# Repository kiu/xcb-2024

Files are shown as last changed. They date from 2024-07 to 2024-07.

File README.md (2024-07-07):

# xcb-2024
The cross communication badge (xcb) was created for a two day internal company conference. Its main purpose was to gamify communication and networking across the 150 participants.

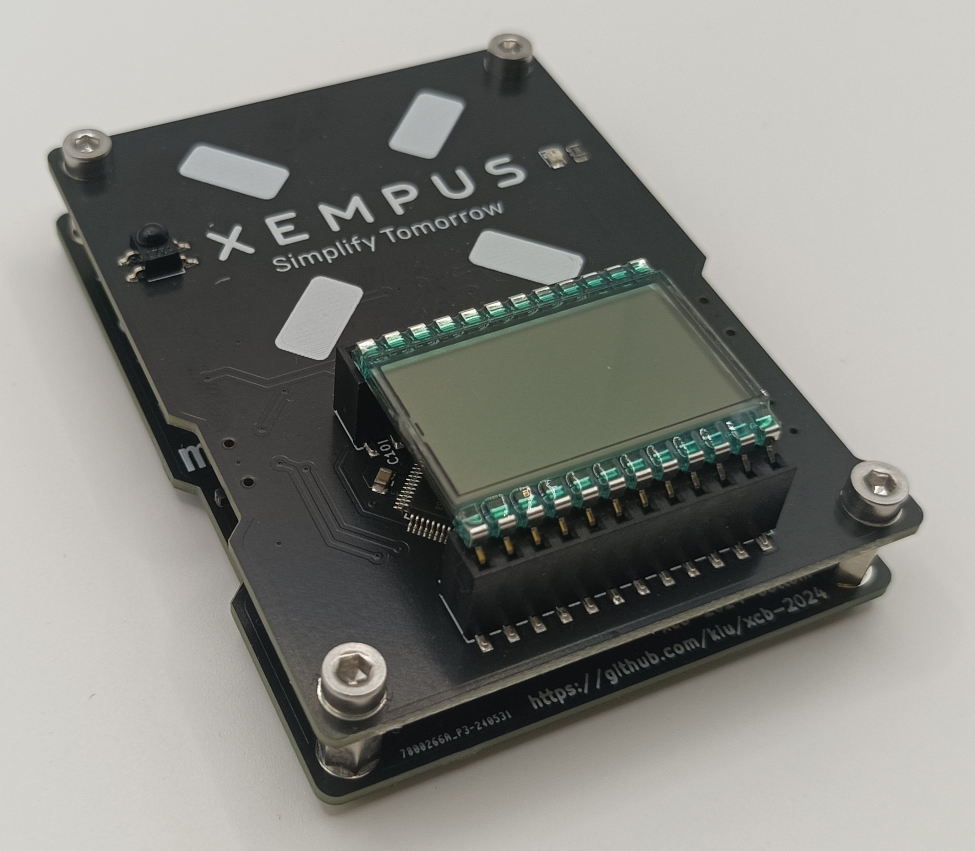
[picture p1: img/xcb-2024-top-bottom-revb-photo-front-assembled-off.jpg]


<sup>Additional images can be found in the [img](img/) directory</sup>

# Features
The badge features three modes: Conference, Play and Sensor.

In <ins>conference mode</ins> each badge transmits its unique ID every 30 seconds. Any badge receiving two transmissions from the same badge within 100 seconds will count this as a unique contact. Due to limited infrared power, close proximity between sender and receiver is assumed. The amount of unique contacts is displayed on the LCD screen to gamify in-person encounters.

In addition secret badges are hidden at the event location, offering a treasure hunt for those who want to explore beyond the main conference tracks. The needed hints are printed on [flyers](xcb-2024-flyer.pdf) handed out with the badge. The discovery of these secret badges is encoded in the display as single segments to easily compare progress between participants.

It was important to me that the badge could be re-used after the conference so I added two additional modes.

In <ins>play mode</ins> the badge features a version of the popular game Simon https://en.wikipedia.org/wiki/Simon_(game) (in Germany known as Senso https://de.wikipedia.org/wiki/Senso_(Spiel)). People can chase a high score, which can also be displayed when in conference mode.

In <ins>sensor mode</ins> the badge transforms into a temperature and humidity display with min/max functionality. Powered by USB the badge can continue to operate in the home or office.

On the back of this stacked PCB assembly (preventing any electrical shorts while wearing) the participants can find a [silk screened word puzzle](img/xcb-2024-bottom-revb-render-back.png) containing the names of the employees of the company.

## Video
There is a short video highlighting all badge features on youtube: https://youtu.be/XA52-lHTVL4

<a href="http://www.youtube.com/watch?feature=player_embedded&v=XA52-lHTVL4" target="_blank">
	xcb-2024 on youtube
</a>

# Hardware
The hardware is [straight forward](kicad/xcb-2024-top-revb-schematic.png). Powered by two CR2032 coin cells or USB, a STM32, a three digit LCD display, an infrared receiver/transmitter, a buzzer, four capacitive touch buttons and a temperature and humidity sensor. All neatly packed into a wearable badge.

# Repository
- [datasheets](datasheets/): Datasheets of most components
- [firmware](firmware/): STM32CubeIDE project
- [kicad](kicad/): KiCad schematics, PCBs and BOM for single+panelized badge and flash adapter
- [tools](tools/): Helper scripts to generate buzzer note table, mass flashing with auto ID increment and masked word puzzle generator

# License
This project is licensed under the Creative Commons Attribution-NonCommercial 3.0 Unported (CC BY-NC 3.0) license. Use of the company name and company logo in any form is not covered by this license.

# Thanks <3
Thanks to Fabian for helping out on the flyer design and Andrii, Maria (+Sebastian), Monika, Niels (+Milla) for working hard doing the final mechanical assembly!

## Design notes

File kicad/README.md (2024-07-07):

# kicad

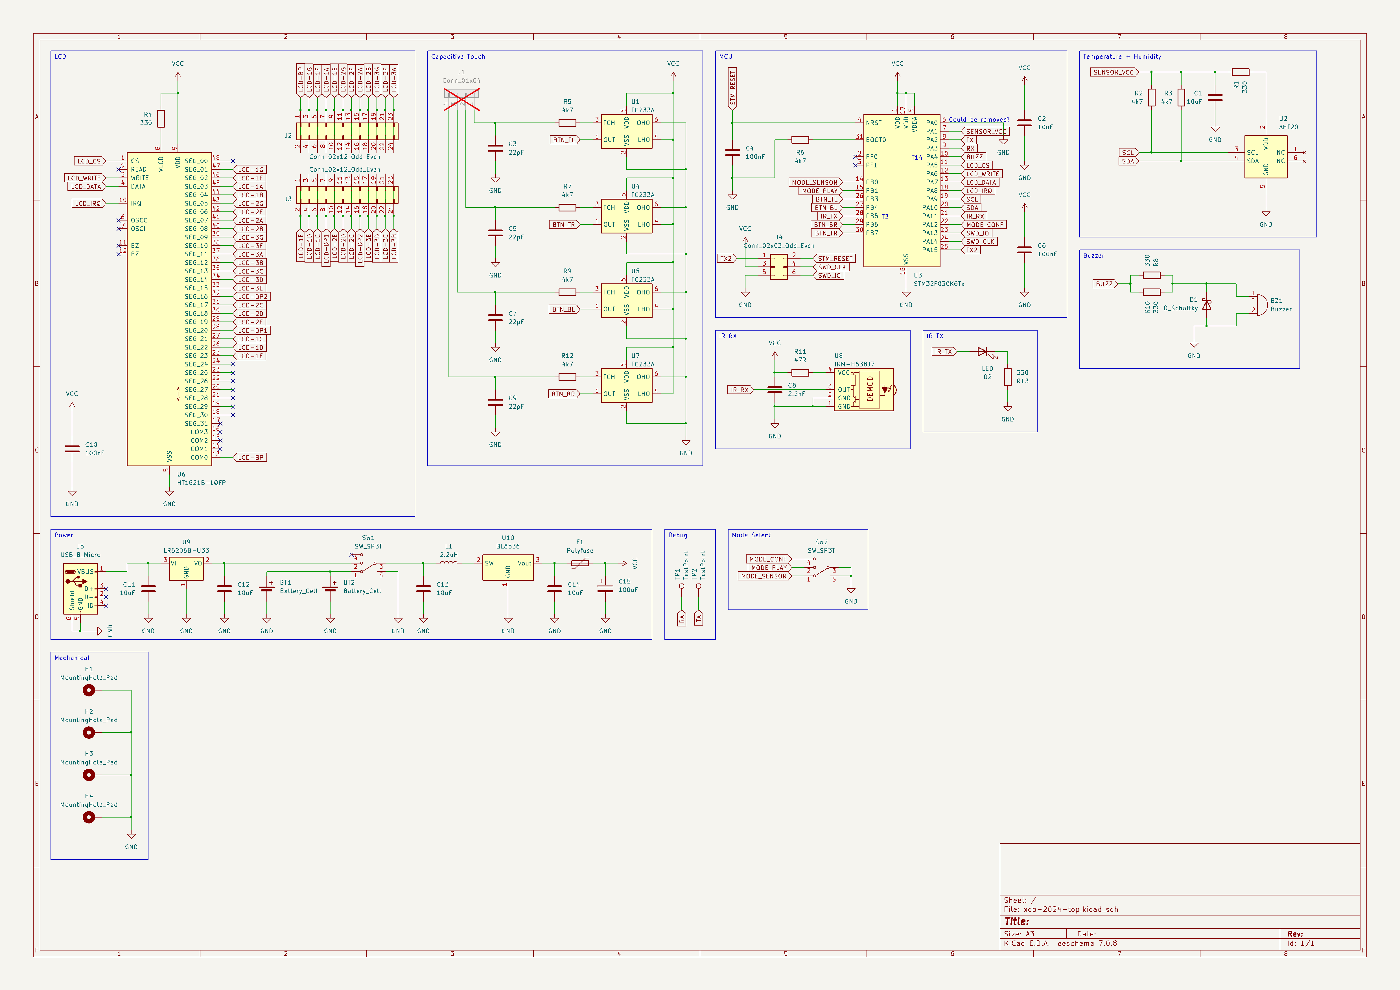
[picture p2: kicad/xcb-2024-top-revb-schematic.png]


<sup>Additional images can be found in the [img](../img/) directory</sup>

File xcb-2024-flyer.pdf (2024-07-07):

### 1. Get started – Set both switches to upper position

### 2. Meet people – It’s a conference, get networking!

### 3. Explore – Find the hidden badges

TREASURE HUNT | CON | QUICK START GUIDE

▢ Burn after reading
▢ Human powered single tracks stay dry
▢ Please do not tap on the glass
▢ There are more than two vertical people transporters ▢ Weary travelers shed the dust of the road
▢ Rich sea creatures read newspapers too
▢ A penny saved is a penny earned
▢ It has been x days since ...
▢ Thirteen letter inception
▢ Find Simon & sing the IT Crowd’s new emergency number by heart

## Find the hidden badges

Set your badge to conference mode (upper position) and begin exploring.
Mischievous Simon has hidden ten badges at our event. It’s up to you to find every single one. Luckily, he left some clues:

show
unique connections

show
treasure [H]unt progress
cycle through all | show [P]lay score

Touch to...

If your badge stays in direct sight of an undiscovered badge for 15
seconds, | you'll | automatically | unlock | that | location.

Ready to brag about your loot? Press the upper right touch button to display your treasure hunt progress.

CONFERENCE MODE | CON

## Gotta Catch ‘Em All!

Set your badge to conference mode (upper position) and start gathering unique contacts.
Get networking and engage in conversations. If your badge stays in sight of an unrecognized badge for two minutes, a new unique contact is registered.
Let’s see how many colleagues you can get to know at our event. Press the upper left touch button to display the total number of connections you have collected.

show
unique connections

show
treasure [H]unt progress
cycle through all | show [P]lay score

Touch to...

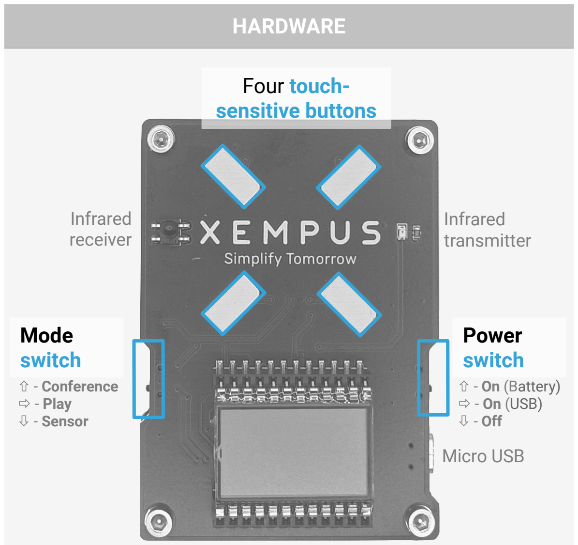
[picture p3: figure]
Mode switch; Power switch; Four touch- sensitive buttons; Micro USB; Infrared receiver; Infrared transmitter; - Conference - Play - Sensor; - On (Battery) - On (USB) - Off; HARDWARE

POWER SUPPLY

PLAY MODE | PLY
SENSOR MODE | SEN

Once the conference is over, you can use your badge as a temperature and/or humidity display or play a game of Simon.

Use the micro-USB socket to power your badge indefinitely.

## Jog your memory!

Set your badge into play mode (centre position) and play a round of Simon (known in Germany as “Senso”).
Choose to start a new sequence or retry the previous one. Your [S]core and eternal [H]igh-score are displayed. Boast your high-score while in conference mode. Power via USB if needed.
new sequence | previous sequence
new sequence | previous sequence

Play...

## How cool is that?!

Once the conference is over, turn your badge into a temperature and/or humidity display.
Power your badge via USB and set it to sensor mode (lower position). The badge updates every few seconds, showing temperature [°C], humidity [h], or cycling through both [°Ch].

I want to turn my badge...

...on (Battery): Power switch to upper position

...on (USB): Power switch to center position

...off: Power switch to lower position

switch between:
Temperature, humidity,
cycle through both

switch between:
Current, lowest and
highest measurement

clear lowest and highest
measurement

Touch to...

save current setting
as default

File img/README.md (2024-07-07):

# xcb-2024



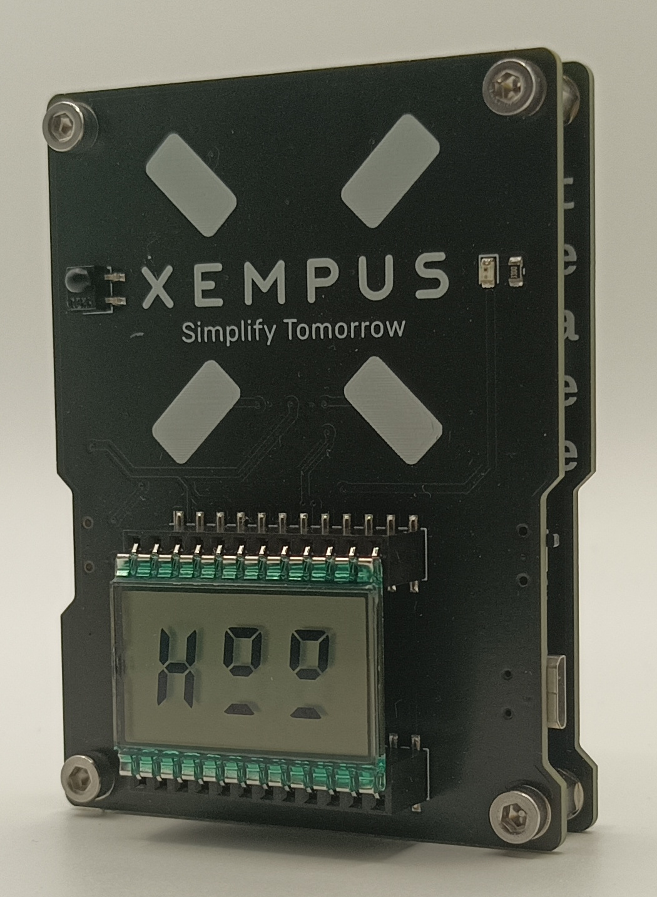
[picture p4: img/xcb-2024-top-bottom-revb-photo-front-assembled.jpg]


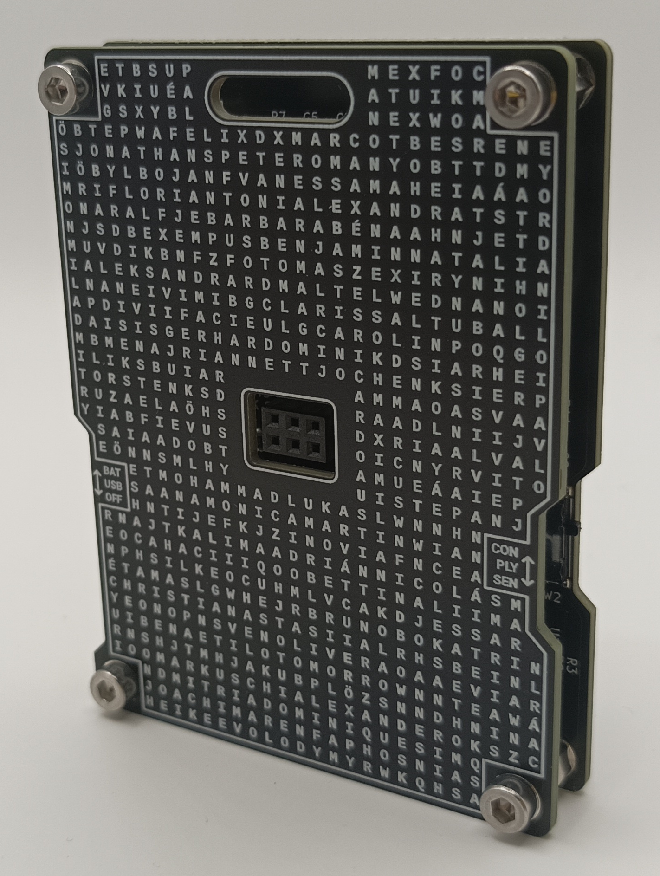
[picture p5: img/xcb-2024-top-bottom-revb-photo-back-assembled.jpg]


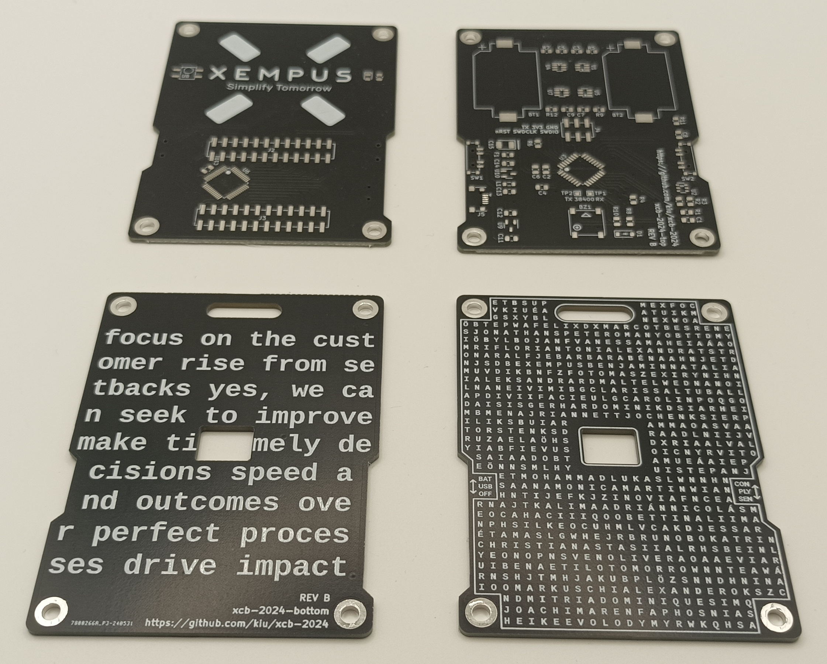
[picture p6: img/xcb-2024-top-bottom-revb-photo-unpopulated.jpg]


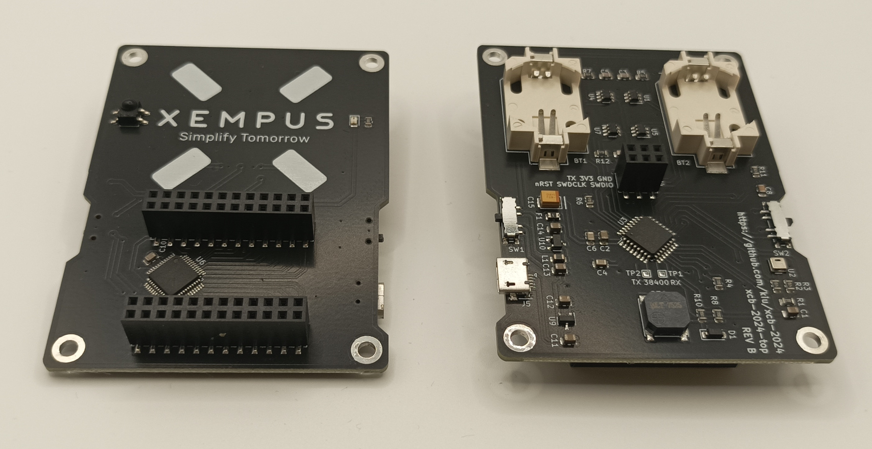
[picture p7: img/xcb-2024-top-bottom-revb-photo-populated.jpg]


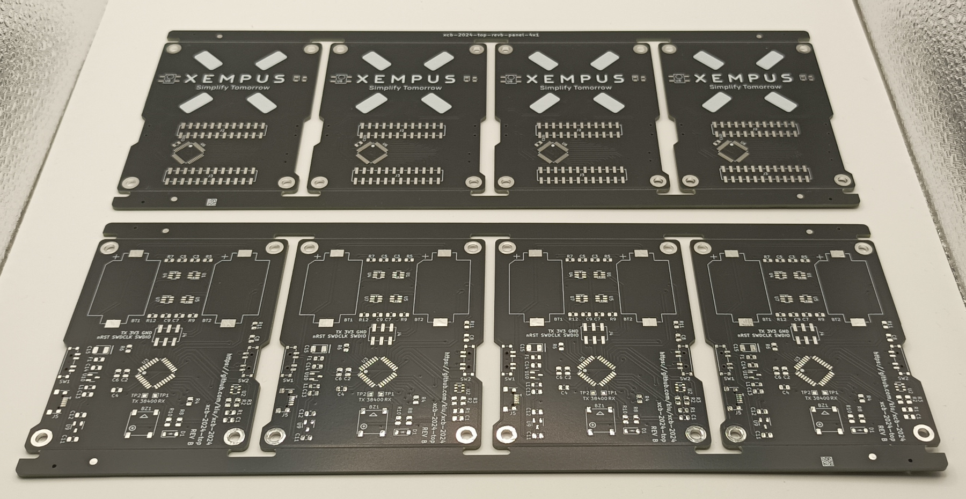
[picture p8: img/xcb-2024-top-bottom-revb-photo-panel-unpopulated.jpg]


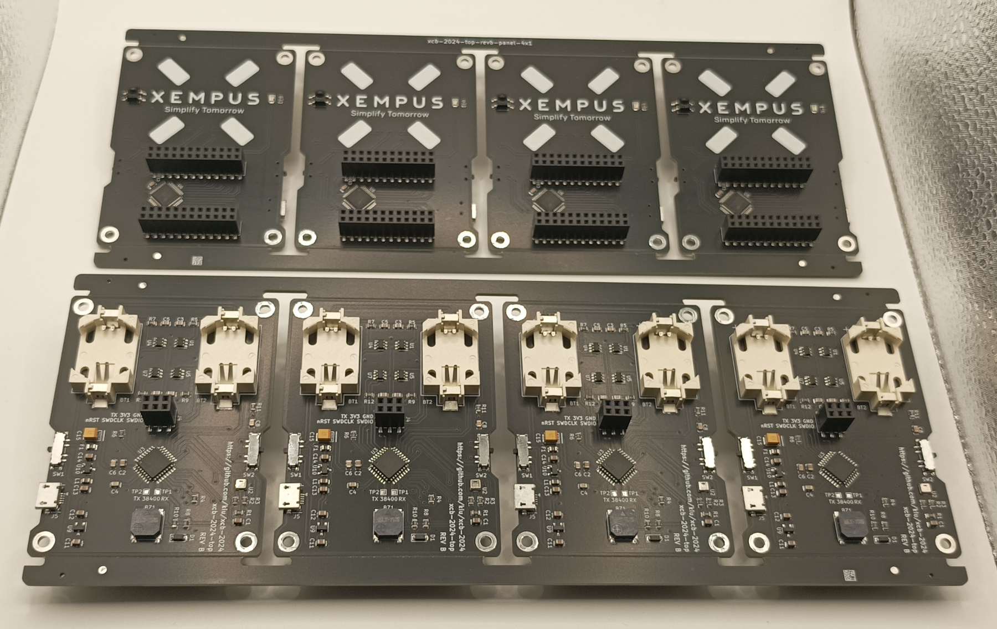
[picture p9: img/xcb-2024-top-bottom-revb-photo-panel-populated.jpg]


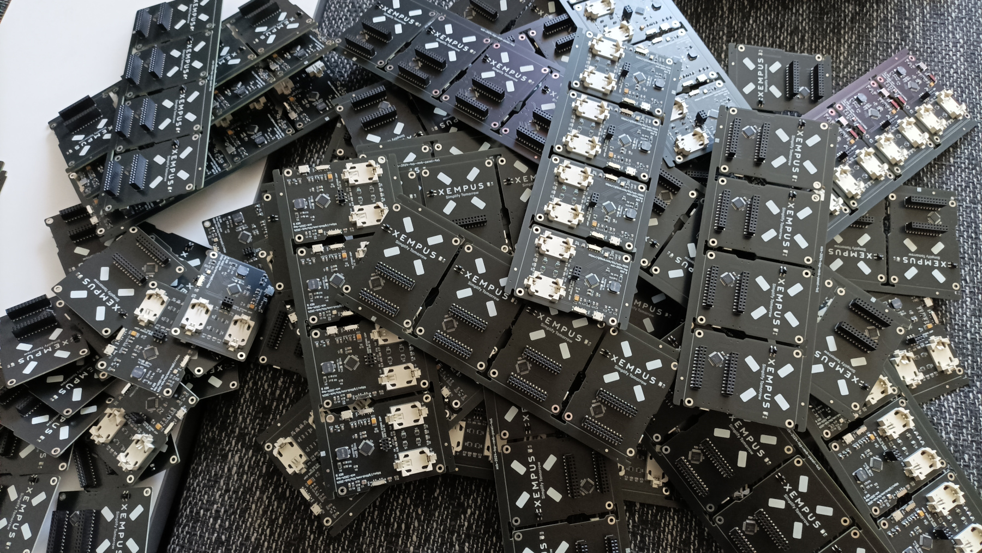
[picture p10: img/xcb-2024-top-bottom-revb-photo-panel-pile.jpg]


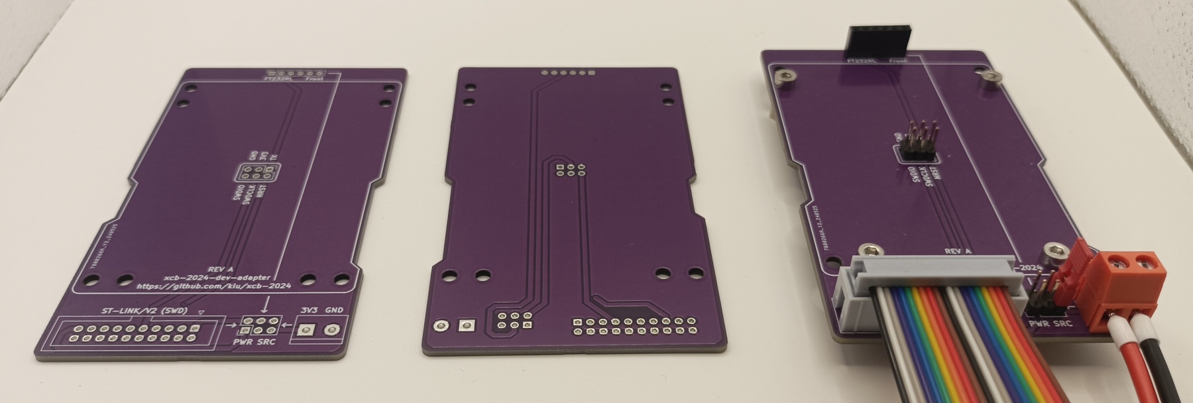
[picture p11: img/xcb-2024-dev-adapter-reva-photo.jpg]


# xcb-2024-top

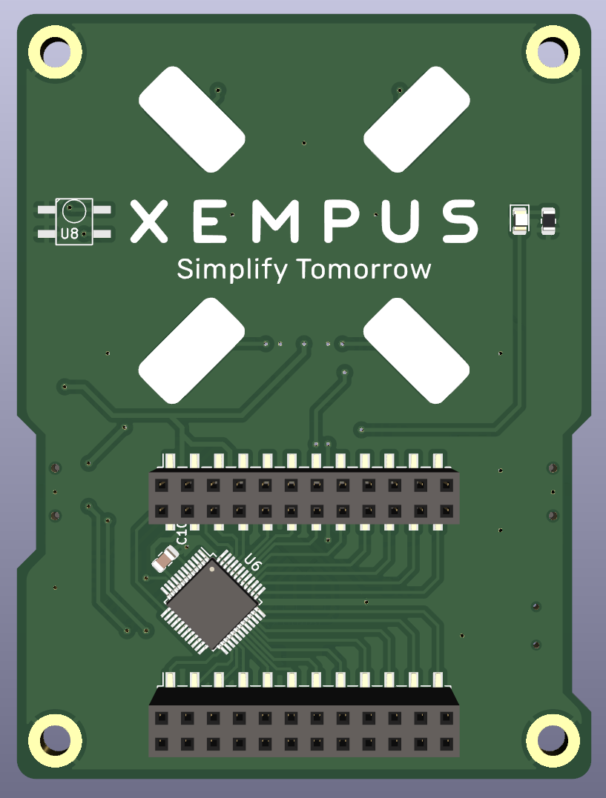
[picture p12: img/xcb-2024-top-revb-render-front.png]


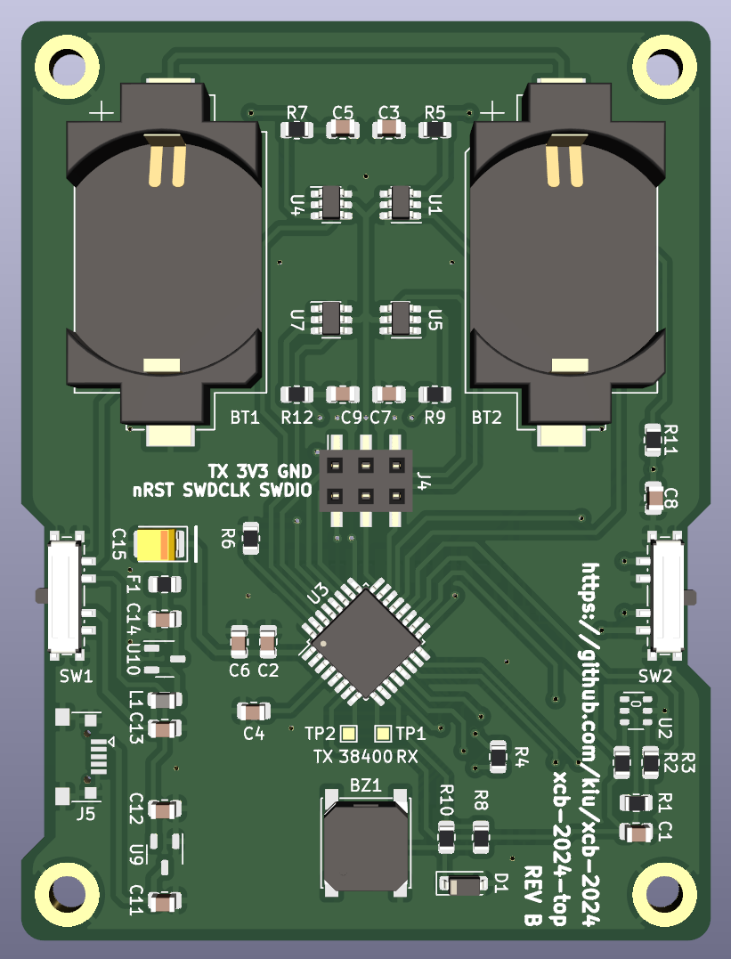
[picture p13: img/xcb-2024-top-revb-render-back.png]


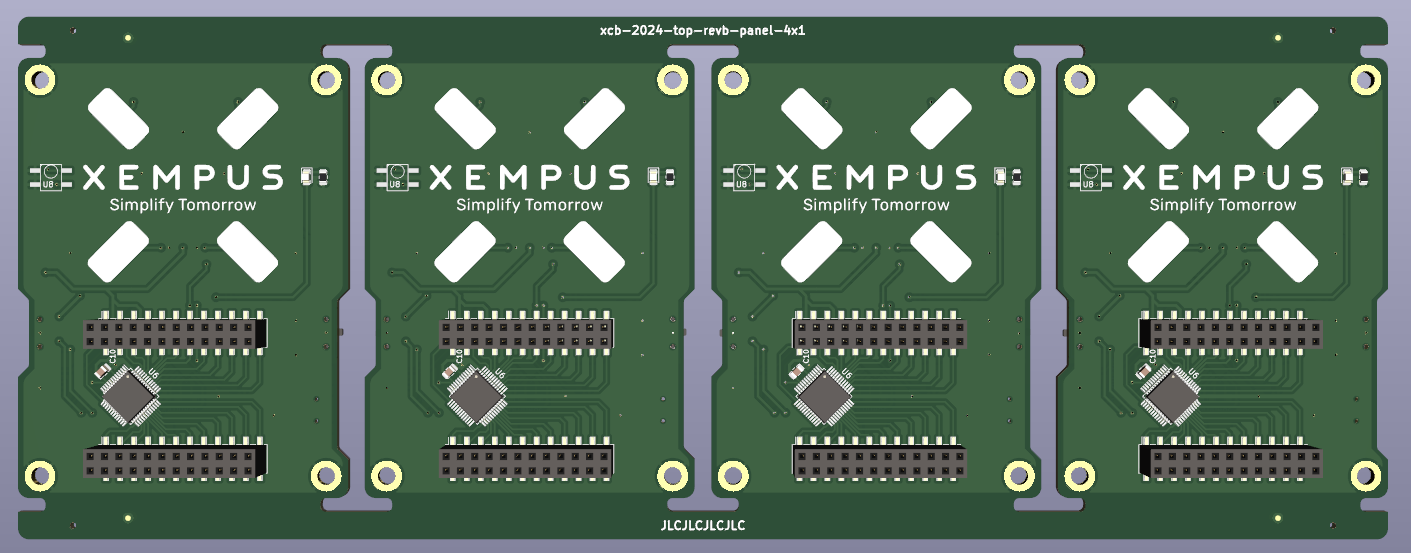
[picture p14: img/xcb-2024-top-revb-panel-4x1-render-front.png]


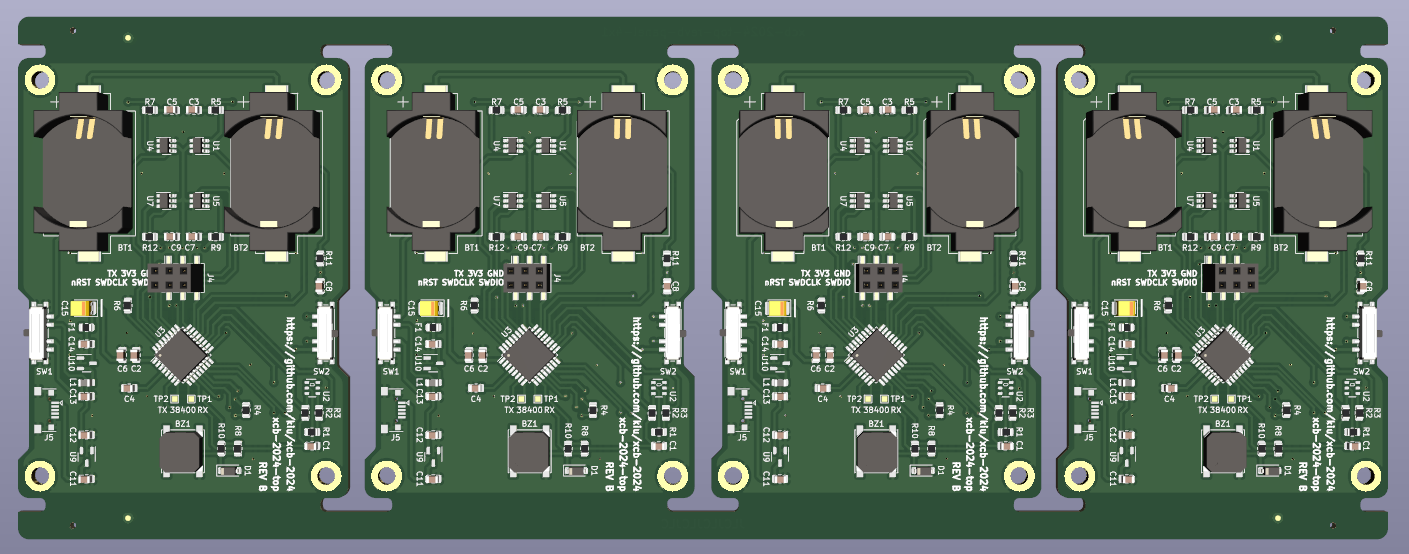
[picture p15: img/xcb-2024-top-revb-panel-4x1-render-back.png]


# xcb-2024-bottom

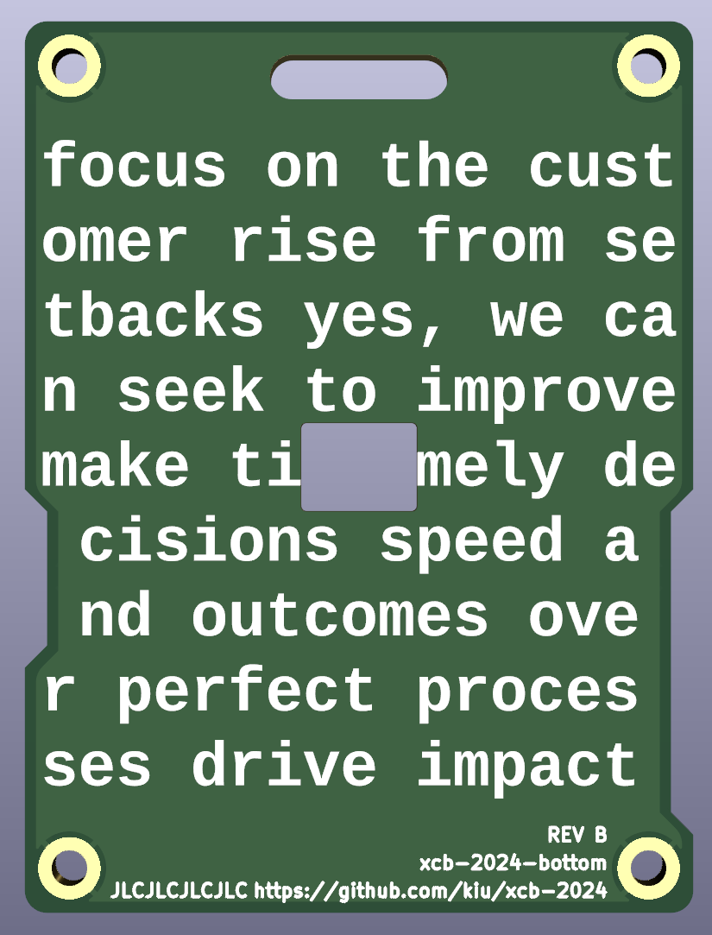
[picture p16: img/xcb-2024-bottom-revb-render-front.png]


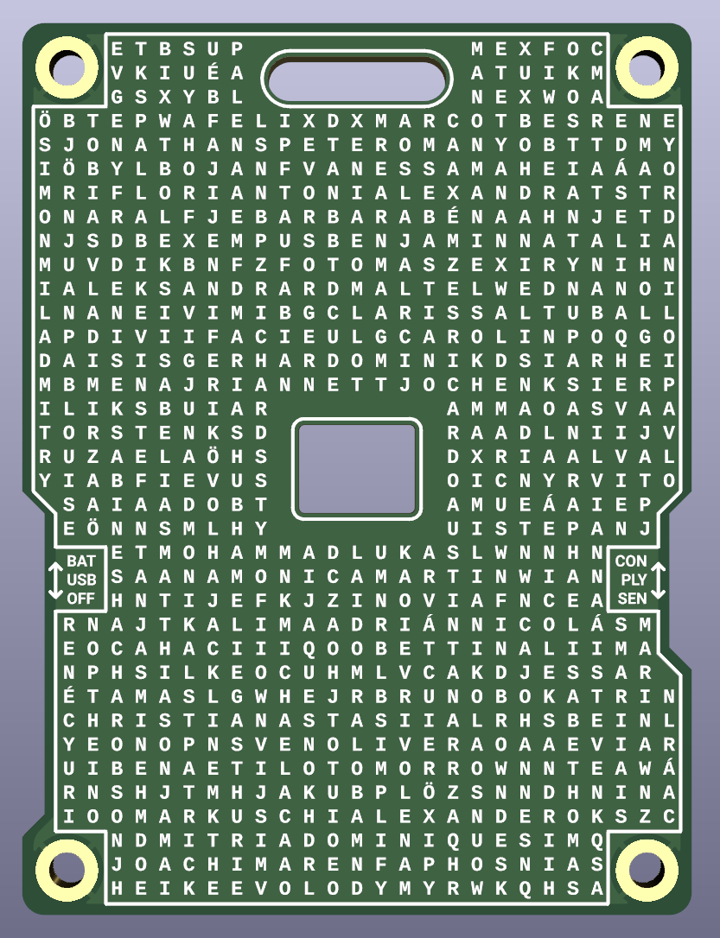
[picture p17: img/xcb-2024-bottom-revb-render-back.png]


# xcb-2024-dev-adapter

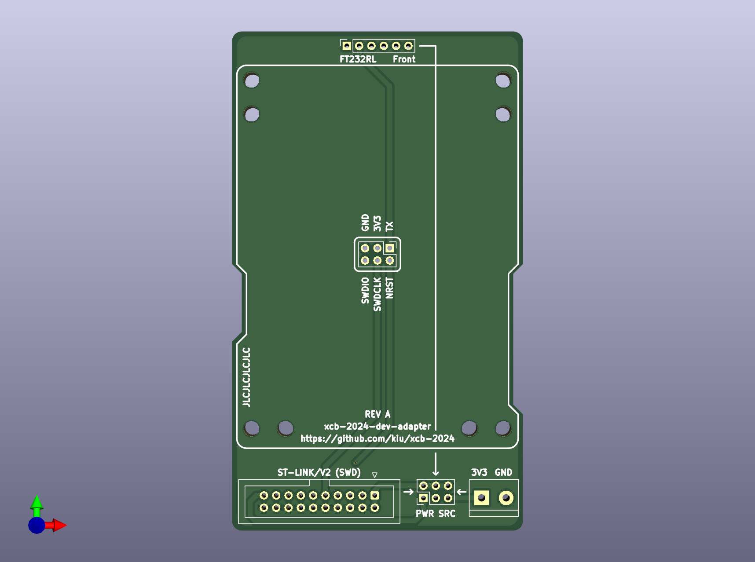
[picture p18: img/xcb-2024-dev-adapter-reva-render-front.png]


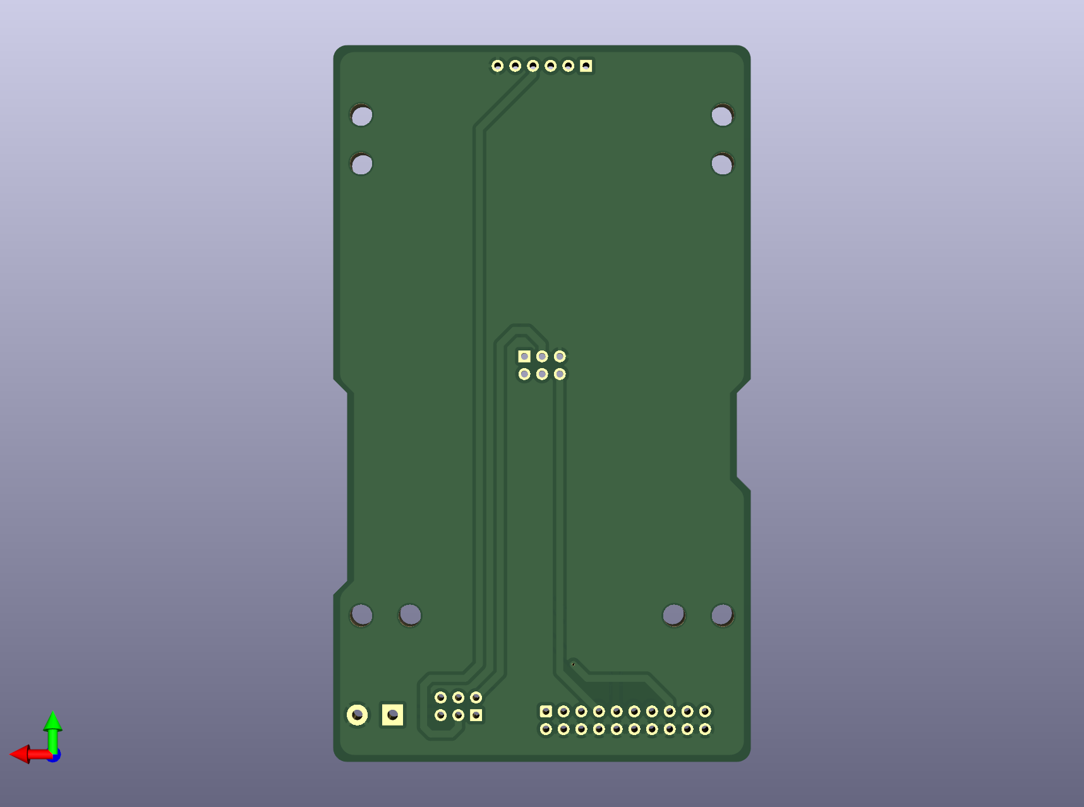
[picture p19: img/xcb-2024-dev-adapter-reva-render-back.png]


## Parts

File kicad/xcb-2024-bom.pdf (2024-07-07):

BOM-PCBA

Page 1

Description | Req | +VAT | Price | Price (sum) | Provider | ID
MOQ 164
Battery Holder 2032 | 2 | 19 | 0,11 € | 0,27 € | C70377
BL8536 | 1 | 19 | 0,08 € | 0,10 € | C97793
LR6206B-U33 | 1 | 19 | 0,01 € | 0,02 € | C5336486
AHT-20 | 1 | 19 | 0,47 € | 0,56 € | C2757850
STM32F030K6T6 | 1 | 19 | 0,57 € | 0,67 € | C46830
Buzzer | 1 | 19 | 0,16 € | 0,19 € | C95299
3 way sliding switch | 2 | 19 | 0,06 € | 0,14 € | C2681569
3 way sliding switch (new) | 2 | 19 | 0,17 € | 0,39 € | C160878
IR RX | 1 | 19 | 0,23 € | 0,28 € | C414640
IR TX 0805 | 1 | 19 | 0,04 € | 0,05 € | C131250
10uF 0805 | 6 | 19 | 0,01 € | 0,06 € | C15850
100nF 0805 | 3 | 19 | 0,00 € | 0,01 € | C49678
2.2nF 0805 | 1 | 19 | 0,00 € | 0,00 € | C36576
HT1621B | 1 | 19 | 0,37 € | 0,44 € | C7532
2x12 2.54 Socket | 2 | 19 | 0,23 € | 0,55 € | C3975157
4k7 0805 | 6 | 19 | 0,00 € | 0,01 € | C17673
330R 0805 | 1 | 19 | 0,00 € | 0,00 € | C17630
90.9R 0805 | 1 | 19 | 0,00 € | 0,00 € | C3000584
47R 0805 | 1 | 19 | 0,00 € | 0,00 € | C17714
Fuse 40mA 0805 | 1 | 19 | 0,05 € | 0,07 € | C2897461
2.2uH 0805 | 1 | 19 | 0,01 € | 0,01 € | C1043
100uF B 3528 Tantalum | 1 | 19 | 0,10 € | 0,12 € | C16133
2x03 2.54 Socket | 1 | 19 | 0,10 € | 0,12 € | C5160818
Schottky Diode | 1 | 19 | 0,02 € | 0,02 € | C8598
TC233A | 4 | 19 | 0,02 € | 0,10 € | C2798022
22pF 0805 | 4 | 19 | 0,01 € | 0,05 € | C1804
Micro USB | 1 | 19 | 0,02 € | 0,02 € | C2681557
| | | | SUM
| | | | 4,28 €
| | | | 701,23 €

www.lcsc.com
www.lcsc.com
www.lcsc.com
www.lcsc.com
www.lcsc.com
www.lcsc.com
www.lcsc.com
www.lcsc.com
www.lcsc.com
www.lcsc.com
www.lcsc.com
www.lcsc.com
www.lcsc.com
www.lcsc.com
www.lcsc.com
www.lcsc.com
www.lcsc.com
www.lcsc.com
www.lcsc.com
www.lcsc.com
www.lcsc.com
www.lcsc.com
www.lcsc.com
www.lcsc.com
www.lcsc.com
www.lcsc.com
www.lcsc.com

### BOM-MISC

### Page 2

Description | Req | +VAT | Price | Price (sum) | Provider | ID

### MOQ 164

LCD | 1 | 0 | 1,29 € | 1,29 € | DE123-RS-20/7.5
M3x8 hex spacer | 4 | 0 | 0,09 € | 0,34 € | TFF-M3X8/DR113
M3x4 hex screw | 8 | 0 | 0,01 € | 0,06 € | M3X4/D912-A2
CR2032 Battery | 2 | 0 | 0,17 € | 0,34 € | B06XVR68R7
Clip | 1 | 0 | 0,23 € | 0,23 € | B001MS928A
| | | | SUM
| | | | 2,26 €
| | | | 370,34 €

### www.tme.eu www.tme.eu www.tme.eu www.amazon.de www.amazon.de

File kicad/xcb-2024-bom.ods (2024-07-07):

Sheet: BOM-PCBA
Description | Req | +VAT | Price | Price (sum) | Provider | ID
 |  |  | MOQ | 164
Battery Holder 2032 | 2 | 19 | 0,11 € | 0,27 € | www.lcsc.com | C70377
BL8536 | 1 | 19 | 0,08 € | 0,10 € | www.lcsc.com | C97793
LR6206B-U33 | 1 | 19 | 0,01 € | 0,02 € | www.lcsc.com | C5336486
AHT-20 | 1 | 19 | 0,47 € | 0,56 € | www.lcsc.com | C2757850
STM32F030K6T6 | 1 | 19 | 0,57 € | 0,67 € | www.lcsc.com | C46830
Buzzer | 1 | 19 | 0,16 € | 0,19 € | www.lcsc.com | C95299
3 way sliding switch | 2 | 19 | 0,06 € | 0,14 € | www.lcsc.com | C2681569
3 way sliding switch (new) | 2 | 19 | 0,17 € | 0,39 € | www.lcsc.com | C160878
IR RX | 1 | 19 | 0,23 € | 0,28 € | www.lcsc.com | C414640
IR TX 0805 | 1 | 19 | 0,04 € | 0,05 € | www.lcsc.com | C131250
10uF 0805 | 6 | 19 | 0,01 € | 0,06 € | www.lcsc.com | C15850
100nF 0805 | 3 | 19 | 0,00 € | 0,01 € | www.lcsc.com | C49678
2.2nF 0805 | 1 | 19 | 0,00 € | 0,00 € | www.lcsc.com | C36576
HT1621B | 1 | 19 | 0,37 € | 0,44 € | www.lcsc.com | C7532
2x12 2.54 Socket | 2 | 19 | 0,23 € | 0,55 € | www.lcsc.com | C3975157
4k7 0805 | 6 | 19 | 0,00 € | 0,01 € | www.lcsc.com | C17673
330R 0805 | 1 | 19 | 0,00 € | 0,00 € | www.lcsc.com | C17630
90.9R 0805 | 1 | 19 | 0,00 € | 0,00 € | www.lcsc.com | C3000584
47R 0805 | 1 | 19 | 0,00 € | 0,00 € | www.lcsc.com | C17714
Fuse 40mA 0805 | 1 | 19 | 0,05 € | 0,07 € | www.lcsc.com | C2897461
2.2uH 0805 | 1 | 19 | 0,01 € | 0,01 € | www.lcsc.com | C1043
100uF B 3528 Tantalum | 1 | 19 | 0,10 € | 0,12 € | www.lcsc.com | C16133
2x03 2.54 Socket | 1 | 19 | 0,10 € | 0,12 € | www.lcsc.com | C5160818
Schottky Diode | 1 | 19 | 0,02 € | 0,02 € | www.lcsc.com | C8598
TC233A | 4 | 19 | 0,02 € | 0,10 € | www.lcsc.com | C2798022
22pF 0805 | 4 | 19 | 0,01 € | 0,05 € | www.lcsc.com | C1804
Micro USB | 1 | 19 | 0,02 € | 0,02 € | www.lcsc.com | C2681557
 |  |  |  | SUM
 |  |  |  | 4,28 €
 |  |  |  | 701,23 €

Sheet: BOM-MISC
Description | Req | +VAT | Price | Price (sum) | Provider | ID
 |  |  | MOQ | 164
LCD | 1 | 0 | 1,29 € | 1,29 € | www.tme.eu | DE123-RS-20/7.5
M3x8 hex spacer | 4 | 0 | 0,09 € | 0,34 € | www.tme.eu | TFF-M3X8/DR113
M3x4 hex screw | 8 | 0 | 0,01 € | 0,06 € | www.tme.eu | M3X4/D912-A2
CR2032 Battery | 2 | 0 | 0,17 € | 0,34 € | www.amazon.de | B06XVR68R7
Clip | 1 | 0 | 0,23 € | 0,23 € | www.amazon.de | B001MS928A
 |  |  |  | SUM
 |  |  |  | 2,26 €
 |  |  |  | 370,34 €

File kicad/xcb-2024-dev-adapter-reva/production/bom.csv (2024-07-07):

Designator | Footprint | Quantity | Value | LCSC Part #
H1, H2, H3, H4, H5, H6, H7, H8 | MountingHole_3.2mm_M3_DIN965 | 8 | MountingHole
J1 | PinSocket_1x06_P2.54mm_Vertical | 1 | Conn_01x06
J2, J4 | PinHeader_2x03_P2.54mm_Vertical | 2 | Conn_02x03_Odd_Even
J3 | IDC-Header_2x10_P2.54mm_Vertical | 1 | Conn_02x10_Odd_Even
J5 | TerminalBlock_bornier-2_P5.08mm | 1 | Screw_Terminal_01x02

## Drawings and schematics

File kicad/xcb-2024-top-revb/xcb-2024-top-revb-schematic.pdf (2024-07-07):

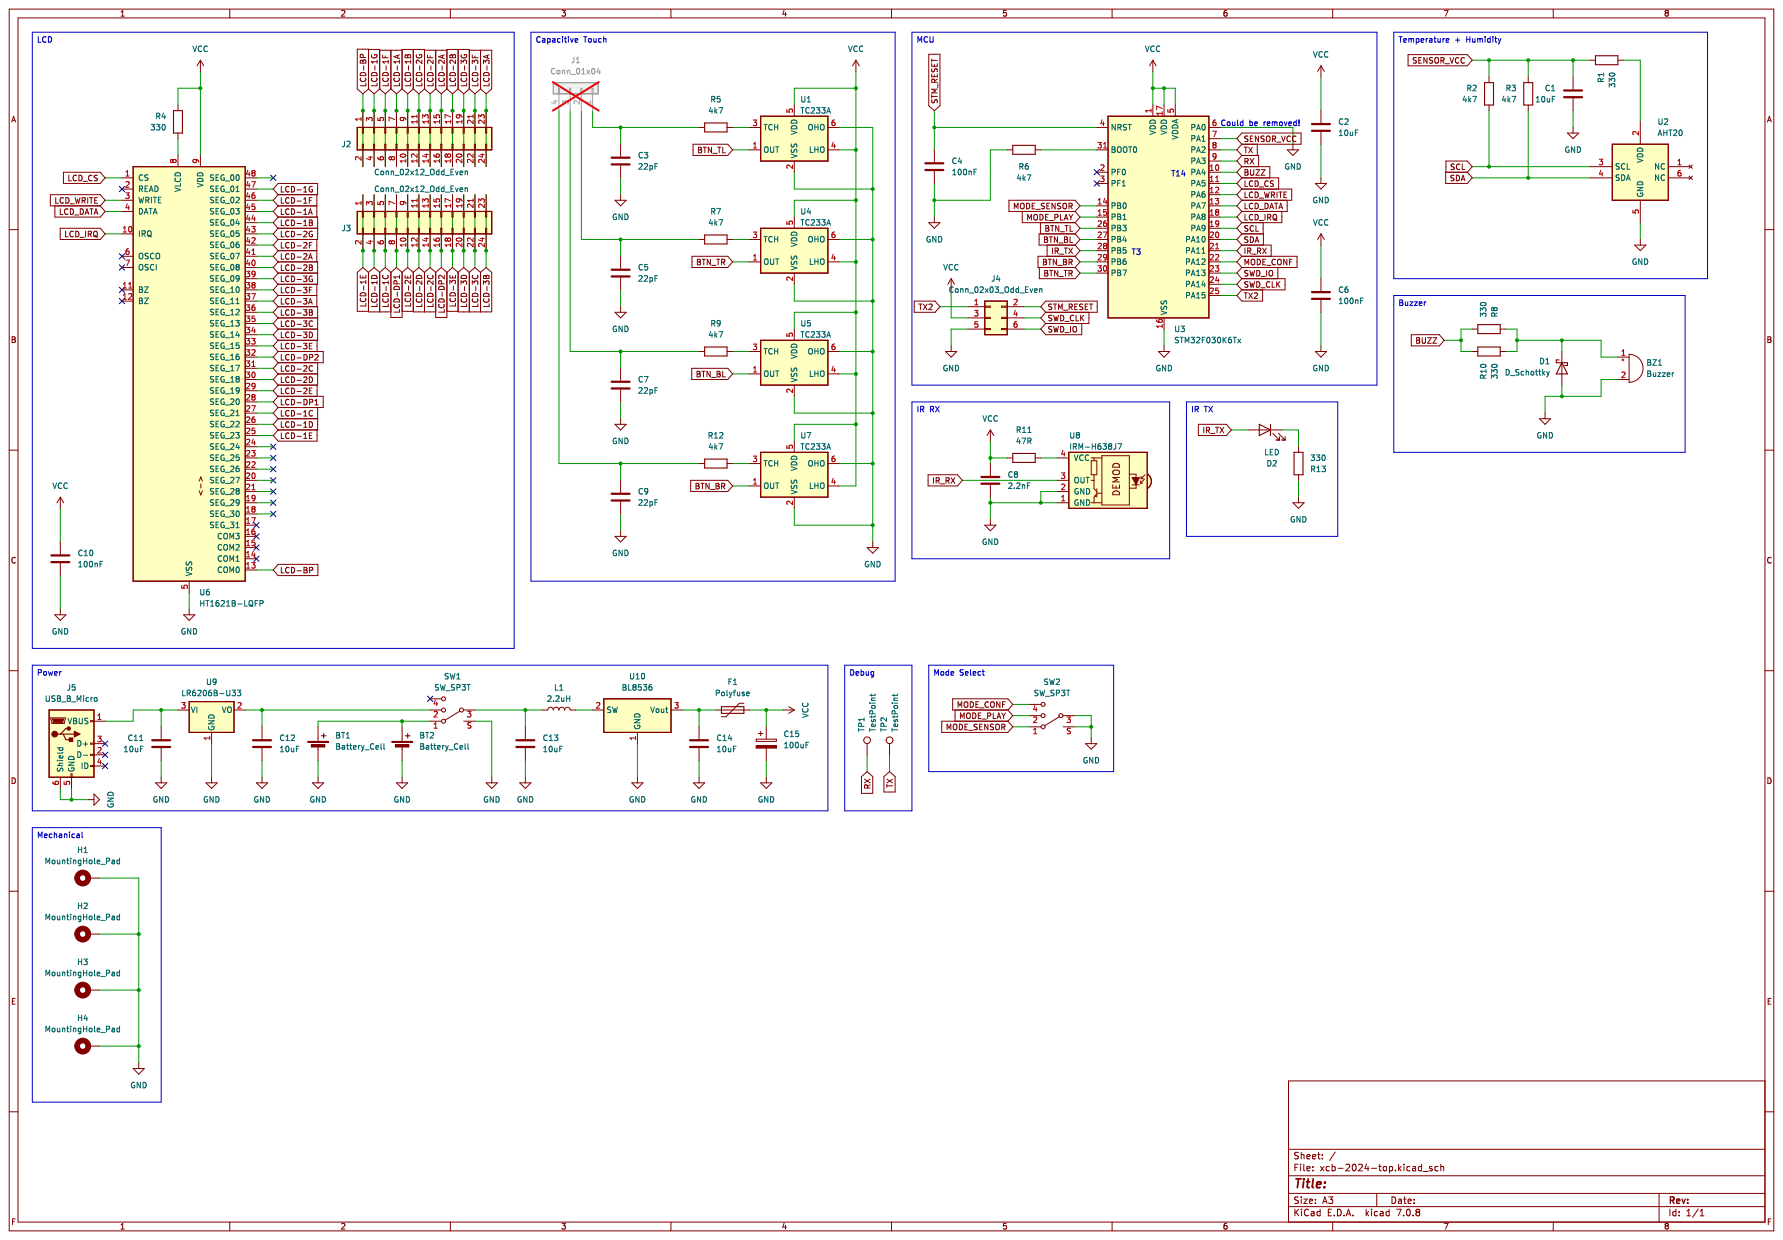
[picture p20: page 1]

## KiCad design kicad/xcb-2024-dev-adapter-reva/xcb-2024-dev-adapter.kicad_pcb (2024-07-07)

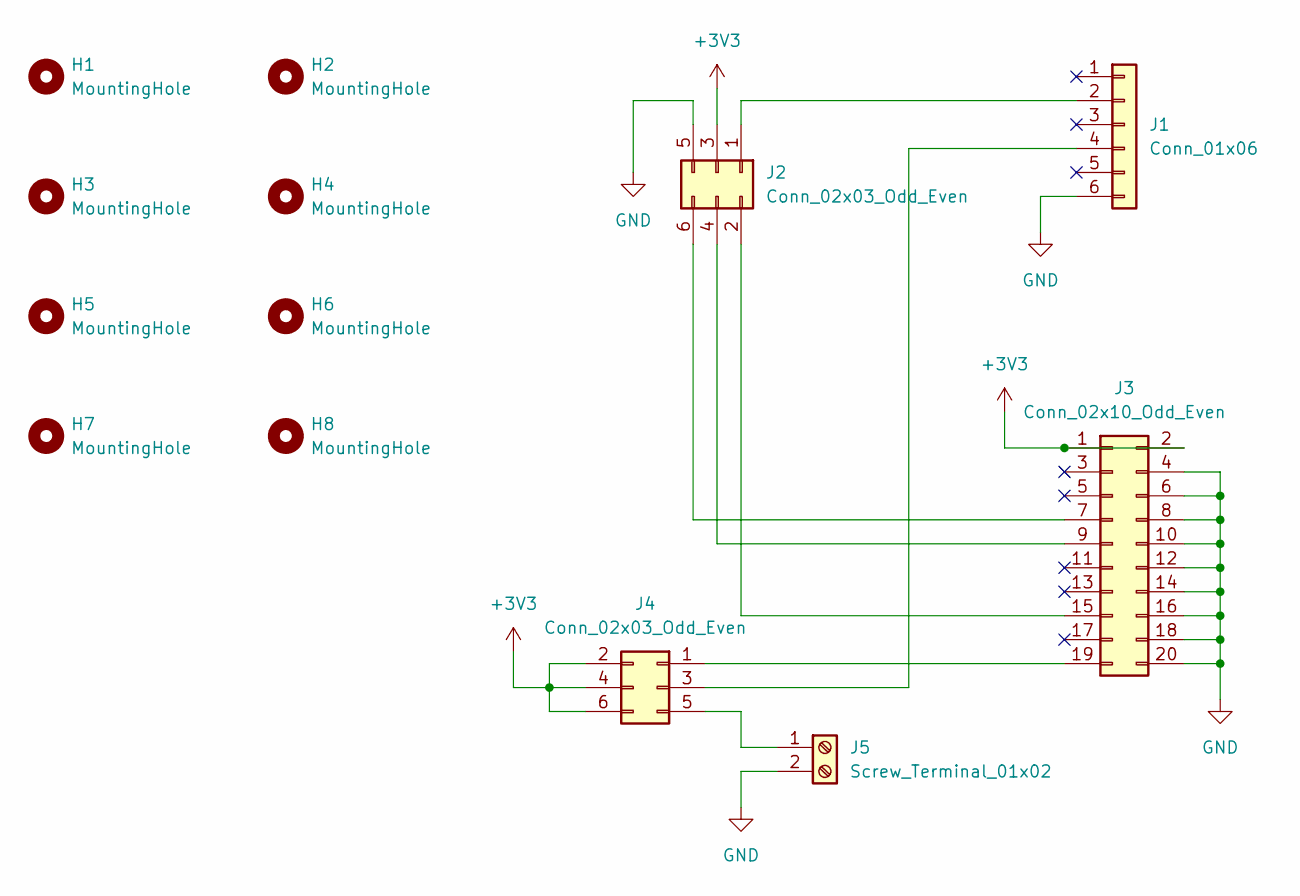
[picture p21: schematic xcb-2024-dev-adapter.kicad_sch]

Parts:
H1, H2, H3, H4, H5, H6, H7, H8: MountingHole; MountingHole_3.2mm_M3_DIN965
J1: Conn_01x06; PinSocket_1x06_P2.54mm_Vertical
J2, J4: Conn_02x03_Odd_Even; PinHeader_2x03_P2.54mm_Vertical
J3: Conn_02x10_Odd_Even; IDC-Header_2x10_P2.54mm_Vertical
J5: Screw_Terminal_01x02; TerminalBlock_bornier-2_P5.08mm

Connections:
+3V3: J2.3, J3.1, J3.2, J4.2, J4.4, J4.6
GND: J1.6, J2.5, J3.4, J3.6, J3.8, J3.10, J3.12, J3.14, J3.16, J3.18, J3.20, J5.2
unnamed: J1.2, J2.1
unnamed: J1.4, J4.3
unnamed: J2.2, J3.15
unnamed: J2.4, J3.9
unnamed: J2.6, J3.7
unnamed: J3.19, J4.1
unnamed: J4.5, J5.1

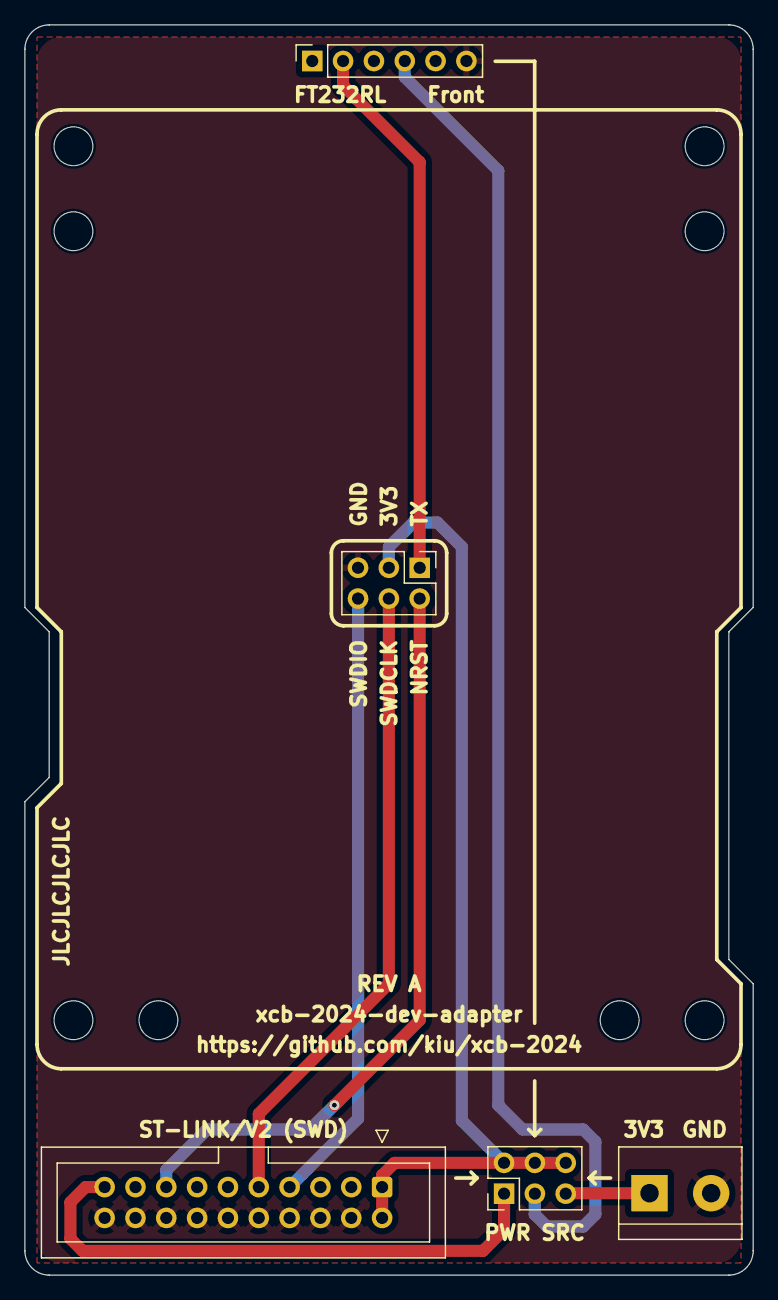
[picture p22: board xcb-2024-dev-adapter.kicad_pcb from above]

Board: 2 copper layers, 60.0 x 103.0 mm, 13 parts (0 on the bottom side), 9 nets.

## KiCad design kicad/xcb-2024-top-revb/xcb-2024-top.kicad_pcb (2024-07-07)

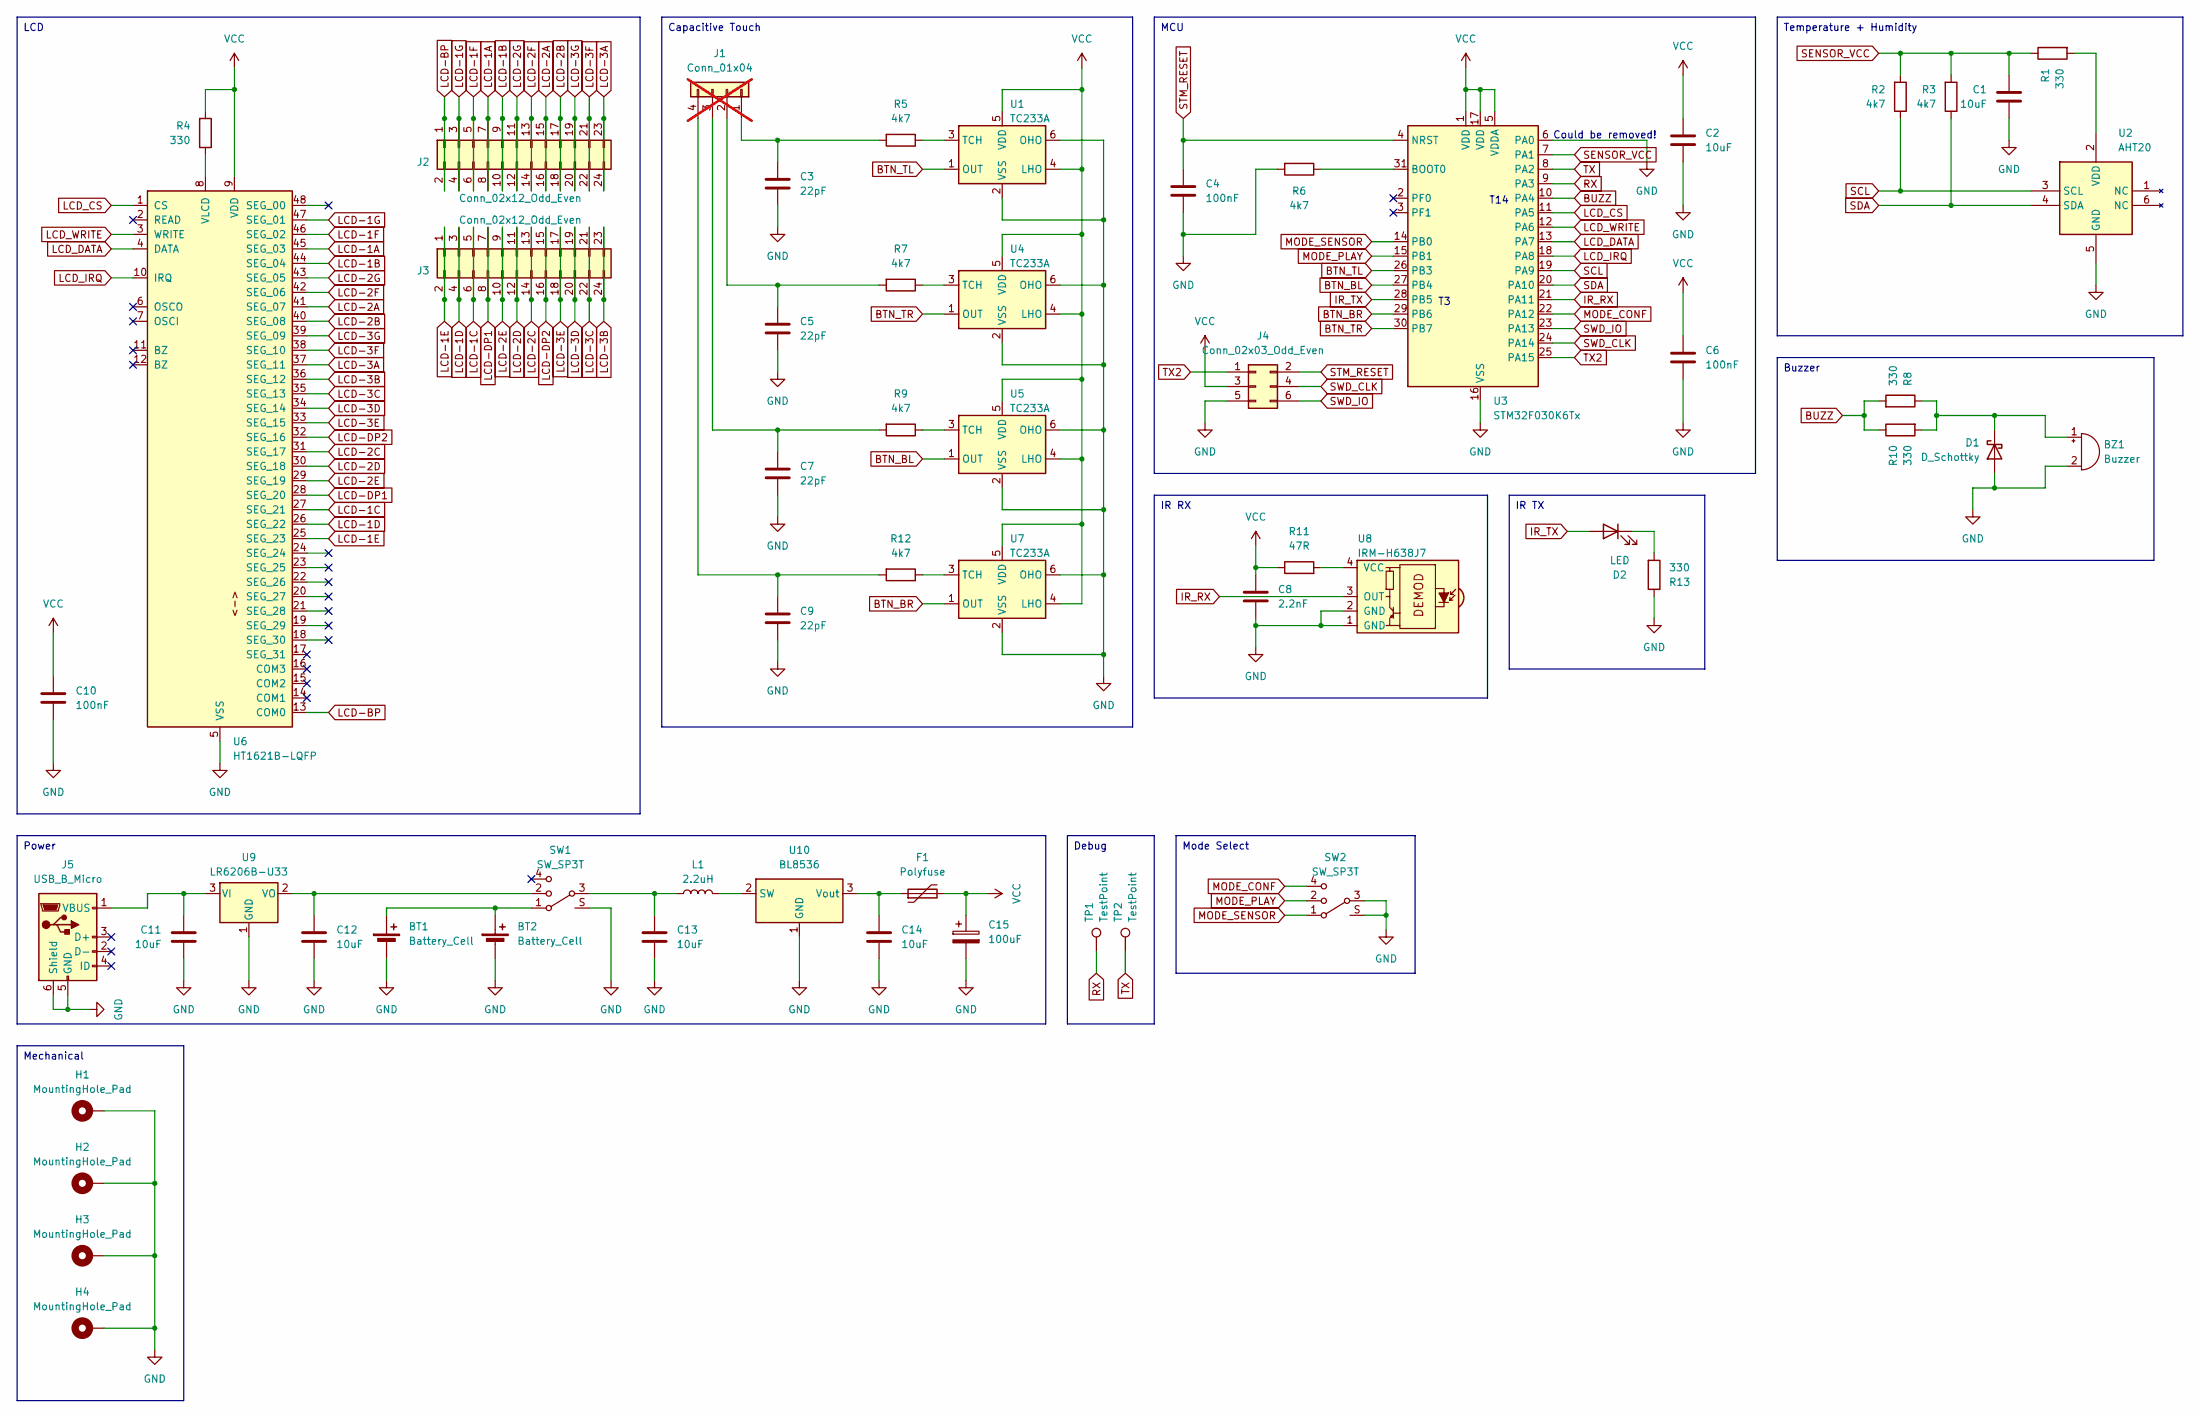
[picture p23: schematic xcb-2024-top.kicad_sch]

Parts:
BT1, BT2: Battery_Cell; BatteryHolder_CR2032-BS-6-1; JLC C70377
BZ1: Buzzer; MLT-7525; JLC C95299
C1, C2, C11, C12, C13, C14: 10uF; C_0805_2012Metric; JLC C15850
C3, C5, C7, C9: 22pF; C_0805_2012Metric; JLC C1804
C4, C6, C10: 100nF; C_0805_2012Metric; JLC C49678
C8: 2.2nF; C_0805_2012Metric; JLC C36576
C15: 100uF; CP_EIA-3528-21_Kemet-B_rotated; JLC C16133
D1: D_Schottky; D_SOD-123; JLC C8598
D2: LED; LED_0805_2012Metric; JLC C131250
F1: Polyfuse; Fuse_0805_2012Metric; JLC C2897461
H1, H2, H3, H4: MountingHole_Pad; MountingHole_3.2mm_M3_DIN965_Pad_TopBottom
J1: Conn_01x04; XEMPUS Logo 4 Touch; not fitted
J2, J3: Conn_02x12_Odd_Even; PinSocket_2x12_P2.54mm_Vertical_SMD_rotated; JLC C3975157
J4: Conn_02x03_Odd_Even; PinSocket_2x03_P2.54mm_Vertical_SMD_rotated; JLC C5160818
J5: USB_B_Micro; USB_Micro_MICRO QTZB5.5_C2681557; JLC C2681557
L1: 2.2uH; L_0805_2012Metric; JLC C1043
R1, R4, R8, R10, R13: 330; R_0805_2012Metric; JLC C17630
R2, R3, R5, R6, R7, R9, R12: 4k7; R_0805_2012Metric; JLC C17673
R11: 47R; R_0805_2012Metric; JLC C17714
SW1, SW2: SW_SP3T; SW_SP3T_SSSS812201; JLC C160878
TP1, TP2: TestPoint; TestPoint_Pad_1.0x1.0mm
U1, U4, U5, U7: TC233A; SOT-23-6_rotated; JLC C2798022
U2: AHT20; JLC C2757850
U3: STM32F030K6Tx; LQFP-32_7x7mm_P0.8mm; JLC C46830
U6: HT1621B-LQFP; LQFP-48_7x7mm_P0.5mm; JLC C7532
U8: IRM-H638J7; JLC C414640
U9: LR6206B-U33; SOT-23-3; JLC C5336486
U10: BL8536; SOT-23-3; JLC C97793

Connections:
BTN_BL: U3.27 (PB4), U5.1 (OUT)
BTN_BR: U3.29 (PB6), U7.1 (OUT)
BTN_TL: U1.1 (OUT), U3.26 (PB3)
BTN_TR: U3.30 (PB7), U4.1 (OUT)
BUZZ: R8.2, R10.1, U3.10 (PA4)
GND: BT1.2 (-), BT2.2 (-), BZ1.2 (+), C1.1, C2.1, C3.1, C4.1, C5.1, C6.1, C7.1, C8.1, C9.1, C10.1, C11.1, C12.1, C13.1, C14.1, C15.2, D1.2 (A), H1.1, H2.1, H3.1, H4.1, J4.5, J5.5 (GND), J5.6 (Shield), R6.2, R13.1, SW1.S, SW2.3, SW2.S, U1.2 (VSS), U1.6 (OHO), U2.5 (GND), U3.6 (PA0), U3.16 (VSS), U3.32 (VSS), U4.2 (VSS), U4.6 (OHO), U5.2 (VSS), U5.6 (OHO), U6.5 (VSS), U7.2 (VSS), U7.6 (OHO), U8.1 (GND), U8.2 (GND), U9.1 (GND), U10.1 (GND)
IR_RX: U3.21 (PA11), U8.3 (OUT)
IR_TX: D2.2 (A), U3.28 (PB5)
LCD-1A: J2.7, J2.8, U6.45 (SEG_03)
LCD-1B: J2.9, J2.10, U6.44 (SEG_04)
LCD-1C: J3.5, J3.6, U6.27 (SEG_21)
LCD-1D: J3.3, J3.4, U6.26 (SEG_22)
LCD-1E: J3.1, J3.2, U6.25 (SEG_23)
LCD-1F: J2.5, J2.6, U6.46 (SEG_02)
LCD-1G: J2.3, J2.4, U6.47 (SEG_01)
LCD-2A: J2.15, J2.16, U6.41 (SEG_07)
LCD-2B: J2.17, J2.18, U6.40 (SEG_08)
LCD-2C: J3.13, J3.14, U6.31 (SEG_17)
LCD-2D: J3.11, J3.12, U6.30 (SEG_18)
LCD-2E: J3.9, J3.10, U6.29 (SEG_19)
LCD-2F: J2.13, J2.14, U6.42 (SEG_06)
LCD-2G: J2.11, J2.12, U6.43 (SEG_05)
LCD-3A: J2.23, J2.24, U6.37 (SEG_11)
LCD-3B: J3.23, J3.24, U6.36 (SEG_12)
LCD-3C: J3.21, J3.22, U6.35 (SEG_13)
LCD-3D: J3.19, J3.20, U6.34 (SEG_14)
LCD-3E: J3.17, J3.18, U6.33 (SEG_15)
LCD-3F: J2.21, J2.22, U6.38 (SEG_10)
LCD-3G: J2.19, J2.20, U6.39 (SEG_09)
LCD-BP: J2.1, J2.2, U6.13 (COM0)
LCD-DP1: J3.7, J3.8, U6.28 (SEG_20)
LCD-DP2: J3.15, J3.16, U6.32 (SEG_16)
LCD_CS: U3.11 (PA5), U6.1 (CS)
LCD_DATA: U3.13 (PA7), U6.4 (DATA)
LCD_IRQ: U3.18 (PA8), U6.10 (IRQ)
LCD_WRITE: U3.12 (PA6), U6.3 (WRITE)
MODE_CONF: SW2.4, U3.22 (PA12)
MODE_PLAY: SW2.2, U3.15 (PB1)
MODE_SENSOR: SW2.1, U3.14 (PB0)
unnamed: BT1.1 (+), BT2.1 (+), SW1.1
unnamed: BZ1.1 (-), D1.1 (K), R8.1, R10.2
unnamed: C13.2, L1.1, SW1.3
unnamed: D2.1 (K), R13.2
unnamed: C3.2, J1.1, R5.2
unnamed: C5.2, J1.2, R7.2
unnamed: C7.2, J1.3, R9.2
unnamed: C9.2, J1.4, R12.2
unnamed: C11.2, J5.1 (VBUS), U9.3 (VI)
unnamed: R5.1, U1.3 (TCH)
unnamed: R1.2, U2.2 (VDD)
unnamed: R6.1, U3.31 (BOOT0)
unnamed: R7.1, U4.3 (TCH)
unnamed: R9.1, U5.3 (TCH)
unnamed: R4.1, U6.8 (VLCD)
unnamed: R12.1, U7.3 (TCH)
unnamed: R11.2, U8.4 (VCC)
unnamed: C12.2, SW1.2, U9.2 (VO)
unnamed: L1.2, U10.2 (SW)
unnamed: C14.2, F1.1, U10.3 (Vout)
RX: TP1.1, U3.9 (PA3)
SCL: R2.1, U2.3 (SCL), U3.19 (PA9)
SDA: R3.1, U2.4 (SDA), U3.20 (PA10)
SENSOR_VCC: C1.2, R1.1, R2.2, R3.2, U3.7 (PA1)
STM_RESET: C4.2, J4.2, U3.4 (NRST)
SWD_CLK: J4.4, U3.24 (PA14)
SWD_IO: J4.6, U3.23 (PA13)
TX: TP2.1, U3.8 (PA2)
TX2: J4.1, U3.25 (PA15)
VCC: C2.2, C6.2, C8.2, C10.2, C15.1, F1.2, J4.3, R4.2, R11.1, U1.4 (LHO), U1.5 (VDD), U3.1 (VDD), U3.5 (VDDA), U3.17 (VDD), U4.4 (LHO), U4.5 (VDD), U5.4 (LHO), U5.5 (VDD), U6.9 (VDD), U7.4 (LHO), U7.5 (VDD)

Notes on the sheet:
MCU
Mechanical
Power
Mode Select
IR RX
LCD
IR TX
Temperature + Humidity
Buzzer
Capacitive Touch
Debug
Could be removed!
T14

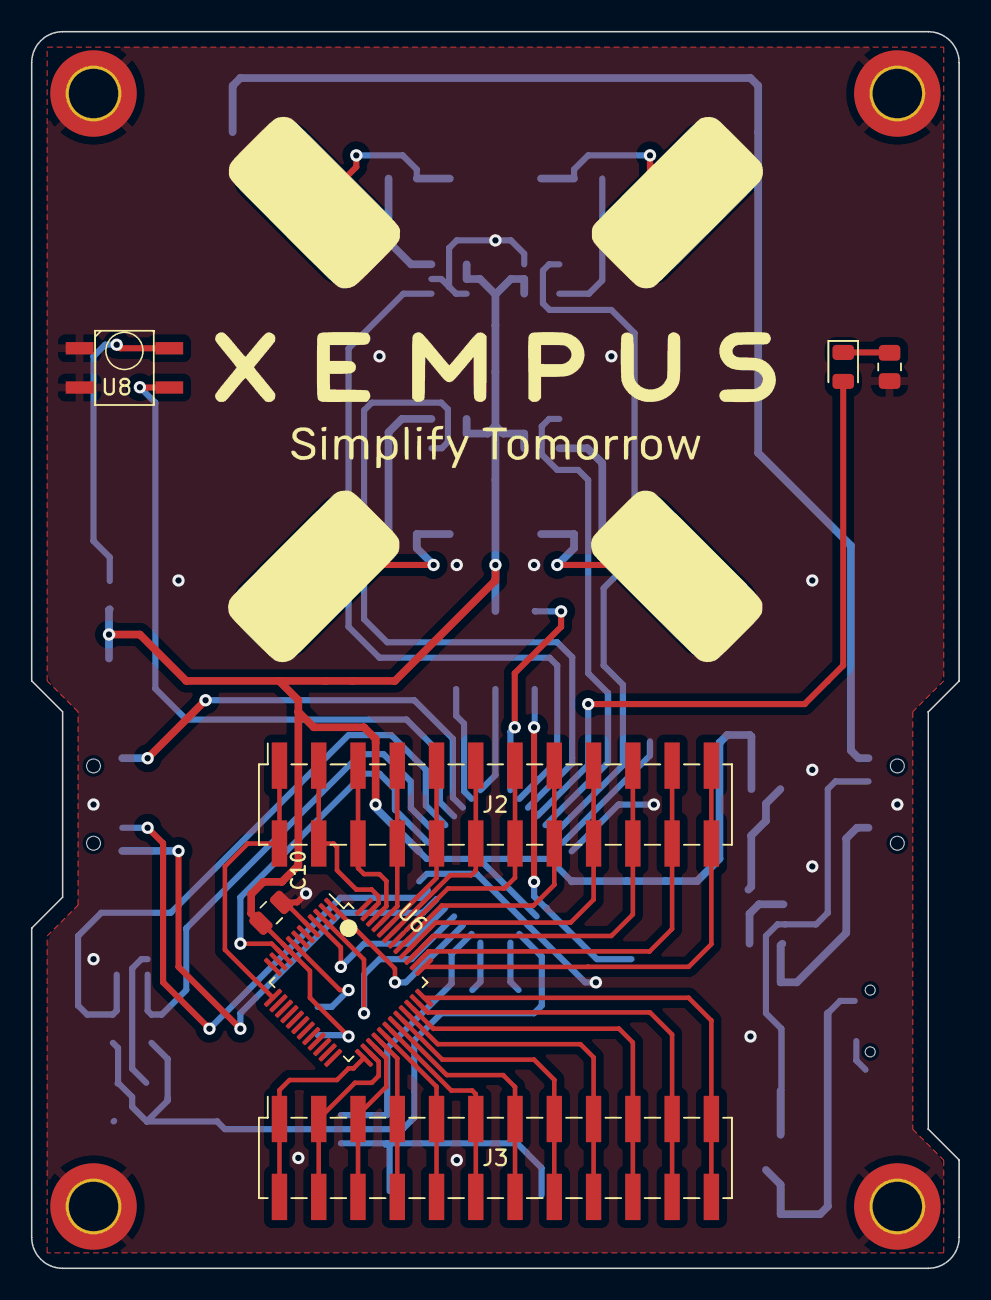
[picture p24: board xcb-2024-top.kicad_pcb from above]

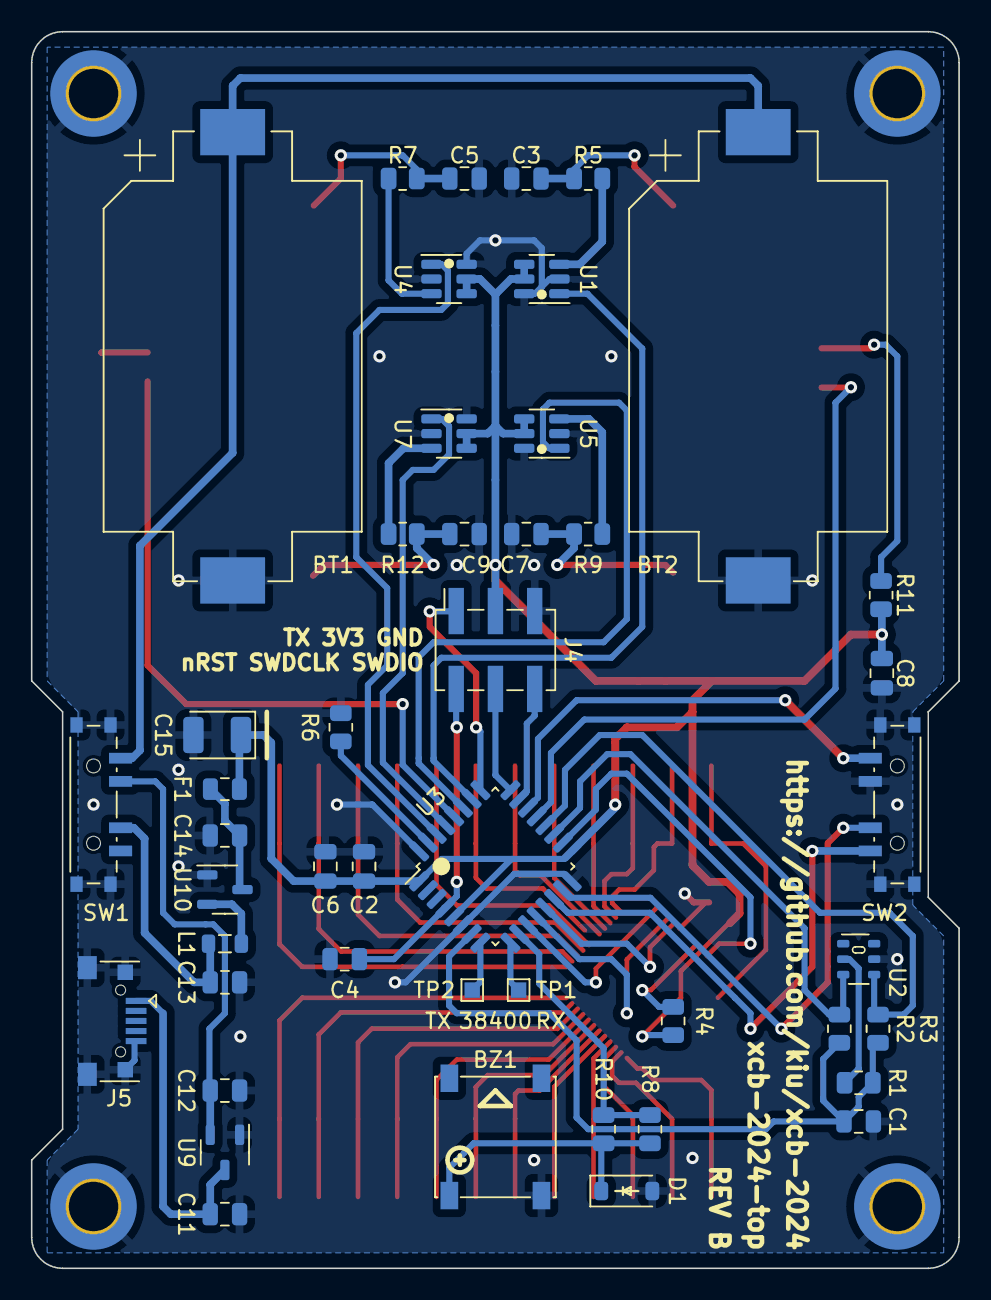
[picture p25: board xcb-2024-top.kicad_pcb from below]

Board: 2 copper layers, 60.0 x 80.0 mm, 58 parts (46 on the bottom side), 69 nets.

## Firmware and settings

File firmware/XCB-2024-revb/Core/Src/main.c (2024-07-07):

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
/* Includes ------------------------------------------------------------------*/
#include "main.h"

/* USER CODE BEGIN Includes */

#include "dev_buzz.h"
#include "dev_eeprom.h"
#include "dev_lcd.h"

#include "mode_conf.h"
#include "mode_play.h"
#include "mode_sensor.h"

/* USER CODE END Includes */

/* USER CODE BEGIN PTD */

typedef enum {
	MODE_INIT, MODE_CONF, MODE_PLAY, MODE_SENSOR
} mode_t;

/* USER CODE END PTD */

/* USER CODE BEGIN PD */

static volatile bool tick = false;
static volatile uint16_t irq_state = 0;

static volatile bool mode_switch = true;
static mode_t mode = MODE_INIT;
static mode_t modeNext = MODE_CONF;

/* USER CODE END PD */

I2C_HandleTypeDef hi2c1;

TIM_HandleTypeDef htim3;
TIM_HandleTypeDef htim14;
TIM_HandleTypeDef htim16;
TIM_HandleTypeDef htim17;

UART_HandleTypeDef huart1;

void SystemClock_Config(void);
static void MX_GPIO_Init(void);
static void MX_I2C1_Init(void);
static void MX_TIM3_Init(void);
static void MX_TIM14_Init(void);
static void MX_TIM16_Init(void);
static void MX_TIM17_Init(void);
static void MX_USART1_UART_Init(void);
/* USER CODE BEGIN PFP */

#if defined(DEBUG)
#define PUTCHAR_PROTOTYPE int __io_putchar(int ch)
#endif

/* USER CODE END PFP */

/* USER CODE BEGIN 0 */

#if defined(DEBUG)
PUTCHAR_PROTOTYPE {
	HAL_UART_Transmit(&huart1, (uint8_t*) &ch, 1, 0xFFFF);
	return ch;
}
#endif

void modeCheck() {
	if (!mode_switch) {
		return;
	}
	HAL_Delay(300);

	uint8_t next = 0xFF;
	uint8_t match = 0;
	if (!HAL_GPIO_ReadPin(MODE_CONF_GPIO_Port, MODE_CONF_Pin)) {
		next = MODE_CONF;
		match++;
	}

	if (!HAL_GPIO_ReadPin(MODE_PLAY_GPIO_Port, MODE_PLAY_Pin)) {
		next = MODE_PLAY;
		match++;
	}
	if (!HAL_GPIO_ReadPin(MODE_SENSOR_GPIO_Port, MODE_SENSOR_Pin)) {
		next = MODE_SENSOR;
		match++;
	}

	if (match == 1) {
		modeNext = next;
		mode_switch = false;
	}
}

void modeChange() {
#if defined(DEBUG)
	printf("M: Mode change: %d --> %d\n", mode, modeNext);
#endif

#if defined(DEBUG)
	printf("M: Mode stop: %d\n", mode);
#endif

	if (mode == MODE_CONF) {
		confStop();
	}
	if (mode == MODE_PLAY) {
		playStop();
	}
	if (mode == MODE_SENSOR) {
		sensorStop();
	}

	lcdShow(0);
	mode = modeNext;

#if defined(DEBUG)
	printf("M: Mode start: %d\n", mode);
#endif

	if (mode == MODE_CONF) {
		lcdShow(lcdChar(0x35)); // CON
		HAL_Delay(1000);
		confStart();
	}
	if (mode == MODE_PLAY) {
		lcdShow(lcdChar(0x36)); // PLY
		HAL_Delay(1000);
		playStart();
	}
	if (mode == MODE_SENSOR) {
		lcdShow(lcdChar(0x37)); // SEN
		HAL_Delay(1000);
		sensorStart();
	}
}

void modeTick() {
//#if defined(DEBUG)
//	printf("M: Mode tick: %d\n", mode);
//#endif

	if (mode == MODE_CONF) {
		confTick();
	}
	if (mode == MODE_PLAY) {
		playTick();
	}
	if (mode == MODE_SENSOR) {
		sensorTick();
	}
}

void buttonClear() {
	irq_state &= ~BTN_TL_Pin;
	irq_state &= ~BTN_TR_Pin;
	irq_state &= ~BTN_BR_Pin;
	irq_state &= ~BTN_BL_Pin;
}

void buttonCheck() {
	uint8_t btn = 0;

	if (irq_state & BTN_TL_Pin) {
		irq_state &= ~BTN_TL_Pin;
		btn |= (1 << 0);
	}
	if (irq_state & BTN_TR_Pin) {
		irq_state &= ~BTN_TR_Pin;
		btn |= (1 << 1);
	}
	if (irq_state & BTN_BR_Pin) {
		irq_state &= ~BTN_BR_Pin;
		btn |= (1 << 2);
	}
	if (irq_state & BTN_BL_Pin) {
		irq_state &= ~BTN_BL_Pin;
		btn |= (1 << 3);
	}

	while (btn > 0) {
		for (uint8_t i = 0; i < 4; i++) {

			if (btn & (1 << i)) {
				btn &= ~(1 << i);
#if defined(DEBUG)
				printf("M: Button: %d\n", i);
#endif

				if (mode == MODE_CONF) {
					confButton(i);
				}
				if (mode == MODE_PLAY) {
					playButton(i);
				}
				if (mode == MODE_SENSOR) {
					sensorButton(i);
				}
			}
		}
	}
}

void HAL_GPIO_EXTI_Callback(uint16_t pin) {
	irq_state |= pin;

	if ((pin & MODE_CONF_Pin) | (pin & MODE_PLAY_Pin) | (pin & MODE_SENSOR_Pin)) {
		mode_switch = true;
	}

	if (pin & LCD_IRQ_Pin) {
		tick = true;
	}

	if (pin & IR_RX_Pin) {
		if (mode == MODE_CONF) {
			confIRRX_gpio_dec();
		}
	}
}

void HAL_TIM_PeriodElapsedCallback(TIM_HandleTypeDef *htim) {
	if (htim == &htim16) {
		confIRTX_htim_enc();
	}

	if (htim == &htim17) {
		confIRRX_htim_dec();
	}
}

badge_t badgeTypeCheck(uint8_t id) {
	if (id >= ID_UNLOCK_START && id <= ID_UNLOCK_END) {
		return BADGE_PARTICIPANT;
	}
	if (id >= ID_TREASURE_START && id <= ID_TREASURE_END) {
		return BADGE_TREASURE;
	}
	return BADGE_OTHER;
}

/* USER CODE END 0 */

/**
 * @brief  The application entry point.
 * @retval int
 */
int main(void) {

	/* MCU Configuration--------------------------------------------------------*/

	/* Reset of all peripherals, Initializes the Flash interface and the Systick. */
	HAL_Init();

	/* Configure the system clock */
	SystemClock_Config();

	/* Initialize all configured peripherals */
	MX_GPIO_Init();
	MX_I2C1_Init();
	MX_TIM3_Init();
	MX_TIM14_Init();
	MX_TIM16_Init();
	MX_TIM17_Init();
	MX_USART1_UART_Init();
	/* USER CODE BEGIN 2 */

#if defined(DEBUG)
	printf("\n");
	printf("https://github.com/kiu/xcb-2024\n");
	printf("M: Firmware: 0x%02X\n", FIRMWARE);
#endif

	eeInit();

	badge_t badge = badgeTypeCheck(eeIDGet());
#if defined(DEBUG)
	printf("M: Badge Type: %d\n", badge);
#endif

	lcdInit();

	uint32_t lcd = 0;

	lcd = 0;
	lcd |= lcdChar(0x2F); // Fxx
	lcd |= lcdDigits_2(16, FIRMWARE, 0, 0, 0);
	lcdShow(lcd);
	buzzInit(htim14);
	HAL_Delay(1200);

	lcd = 0;
	lcd |= lcdChar(0x39); // Uxx
	lcd |= lcdDigits_2(16, eeIDGet(), 0, 0, 0);
	lcdShow(lcd);
	HAL_Delay(1200);

	sensorInit(hi2c1);

	confInit(htim3, htim16, htim17);

	if (badge != BADGE_PARTICIPANT) {
		modeNext = MODE_CONF;
		modeChange();
	}

	/* USER CODE END 2 */

	/* Infinite loop */
	/* USER CODE BEGIN WHILE */
	while (1) {
		/* USER CODE END WHILE */

		/* USER CODE BEGIN 3 */
		if (badge == BADGE_PARTICIPANT) {
			buttonCheck();
			modeCheck();
			if (mode != modeNext) {
				modeChange();
			}
		}

		if (tick) {
			tick = false;
			modeTick();
		}

#if !defined(DEBUG)
		if (confAllowSleep()) {
			HAL_PWR_EnterSTOPMode(PWR_LOWPOWERREGULATOR_ON, PWR_STOPENTRY_WFI);
		}
#endif

	}

	return 0;

	/* USER CODE END 3 */
}

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


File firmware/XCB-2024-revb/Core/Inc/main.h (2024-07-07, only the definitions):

#define FIRMWARE 0x01
#define BUTTON_PRESS_DELAY 150
#define ID_UNLOCK_START 0x01
#define ID_UNLOCK_END 0xDF
#define ID_TREASURE_START 0xE0
#define ID_TREASURE_END 0xEE
#define ID_CMD_WIPE 0xF0
#define ID_CMD_TEST 0xF8
#define SENSOR_VCC_Pin GPIO_PIN_1
#define SENSOR_VCC_GPIO_Port GPIOA
#define BUZZ_Pin GPIO_PIN_4
#define BUZZ_GPIO_Port GPIOA
#define LCD_CS_Pin GPIO_PIN_5
#define LCD_CS_GPIO_Port GPIOA
#define LCD_WRITE_Pin GPIO_PIN_6
#define LCD_WRITE_GPIO_Port GPIOA
#define LCD_DATA_Pin GPIO_PIN_7
#define LCD_DATA_GPIO_Port GPIOA
#define MODE_SENSOR_Pin GPIO_PIN_0
#define MODE_SENSOR_GPIO_Port GPIOB
#define MODE_SENSOR_EXTI_IRQn EXTI0_1_IRQn
#define MODE_PLAY_Pin GPIO_PIN_1
#define MODE_PLAY_GPIO_Port GPIOB
#define MODE_PLAY_EXTI_IRQn EXTI0_1_IRQn
#define LCD_IRQ_Pin GPIO_PIN_8
#define LCD_IRQ_GPIO_Port GPIOA
#define LCD_IRQ_EXTI_IRQn EXTI4_15_IRQn
#define IR_RX_Pin GPIO_PIN_11
#define IR_RX_GPIO_Port GPIOA
#define IR_RX_EXTI_IRQn EXTI4_15_IRQn
#define MODE_CONF_Pin GPIO_PIN_12
#define MODE_CONF_GPIO_Port GPIOA
#define MODE_CONF_EXTI_IRQn EXTI4_15_IRQn
#define BTN_TL_Pin GPIO_PIN_3
#define BTN_TL_GPIO_Port GPIOB
#define BTN_TL_EXTI_IRQn EXTI2_3_IRQn
#define BTN_BL_Pin GPIO_PIN_4
#define BTN_BL_GPIO_Port GPIOB
#define BTN_BL_EXTI_IRQn EXTI4_15_IRQn
#define IR_TX_Pin GPIO_PIN_5
#define IR_TX_GPIO_Port GPIOB
#define BTN_BR_Pin GPIO_PIN_6
#define BTN_BR_GPIO_Port GPIOB
#define BTN_BR_EXTI_IRQn EXTI4_15_IRQn
#define BTN_TR_Pin GPIO_PIN_7
#define BTN_TR_GPIO_Port GPIOB
#define BTN_TR_EXTI_IRQn EXTI4_15_IRQn

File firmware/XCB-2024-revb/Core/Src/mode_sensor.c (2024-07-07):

/*
 * mode_sensor.c
 *
 *  Created on: Jun 2, 2024
 *      Author: kiu
 */

#include "mode_sensor.h"

#include "dev_buzz.h"
#include "dev_eeprom.h"
#include "dev_lcd.h"

static I2C_HandleTypeDef sensor_hi2c1;

static int16_t sensor_temp_cur;
static int16_t sensor_temp_max;
static int16_t sensor_temp_min;

static int16_t sensor_humid_cur;
static int16_t sensor_humid_max;
static int16_t sensor_humid_min;

static bool sensor_i2c_reset = true;
static bool sensor_show_flip = false;
static uint8_t sensor_tick_count = 0;

typedef enum {
	SENSOR_SHOW_CYCLE, SENSOR_SHOW_TEMPERATURE, SENSOR_SHOW_HUMIDTY
} sensor_show_type_t;

static sensor_show_type_t sensor_show_type = SENSOR_SHOW_CYCLE;

typedef enum {
	SENSOR_SHOW_CURRENT, SENSOR_SHOW_MIN, SENSOR_SHOW_MAX,
} sensor_show_value_t;

static sensor_show_value_t sensor_show_value = SENSOR_SHOW_CURRENT;

// ----------------------------------------------------------------------------

void sensorClear() {
	sensor_temp_cur = 0x7FFF;
	sensor_temp_max = 0x7FFF;
	sensor_temp_min = 0x7FFF;
	sensor_humid_cur = 0x7FFF;
	sensor_humid_max = 0x7FFF;
	sensor_humid_min = 0x7FFF;
}

void sensorUpdateLCD() {
	if (sensor_show_type == SENSOR_SHOW_TEMPERATURE) {
		int16_t value = 0;
		if (sensor_show_value == SENSOR_SHOW_CURRENT) {
			value = sensor_temp_cur;
		}
		if (sensor_show_value == SENSOR_SHOW_MIN) {
			value = sensor_temp_min;
		}
		if (sensor_show_value == SENSOR_SHOW_MAX) {
			value = sensor_temp_max;
		}

		// 23.5 | -23
		if (value >= 0) {
			lcdShow(lcdDigits_3(10, value, 0, 1, 0));
		} else {
			lcdShow(lcdDigits_3(10, value / 10, 0, 0, 1));
		}
	}

	if (sensor_show_type == SENSOR_SHOW_HUMIDTY) {
		int16_t value = 0;
		if (sensor_show_value == SENSOR_SHOW_CURRENT) {
			value = sensor_humid_cur;
		}
		if (sensor_show_value == SENSOR_SHOW_MIN) {
			value = sensor_humid_min;
		}
		if (sensor_show_value == SENSOR_SHOW_MAX) {
			value = sensor_humid_max;
		}

		// 45.3
		lcdShow(lcdDigits_3(10, value, 0, 1, 0));
	}

	if (sensor_show_type == SENSOR_SHOW_CYCLE) {
		sensor_show_flip = !sensor_show_flip;

		// 23.5 | -23 | 45h
		if (sensor_show_flip) {
			int16_t value = 0;
			if (sensor_show_value == SENSOR_SHOW_CURRENT) {
				value = sensor_temp_cur;
			}
			if (sensor_show_value == SENSOR_SHOW_MIN) {
				value = sensor_temp_min;
			}
			if (sensor_show_value == SENSOR_SHOW_MAX) {
				value = sensor_temp_max;
			}

			if (value >= 0) {
				lcdShow(lcdDigits_3(10, value, 0, 1, 0));
			} else {
				lcdShow(lcdDigits_3(10, value / 10, 0, 0, 1));
			}
		} else {
			int16_t value = 0;
			if (sensor_show_value == SENSOR_SHOW_CURRENT) {
				value = sensor_humid_cur;
			}
			if (sensor_show_value == SENSOR_SHOW_MIN) {
				value = sensor_humid_min;
			}
			if (sensor_show_value == SENSOR_SHOW_MAX) {
				value = sensor_humid_max;
			}
			uint32_t lcd = 0;
			lcd |= lcdDigits_3(10, value / 10 * 10, 0, 0, 0);
			lcd &= ~lcdChar(0x00);
			lcd |= lcdChar(0x42);
			lcdShow(lcd);
		}
	}

}

void sensorButtonPressed(uint16_t lcd_char) {
	lcdShow(lcdChar(lcd_char));
	HAL_Delay(BUTTON_PRESS_DELAY);
	sensor_tick_count = SENSOR_CYCLE_S;
}

void sensorButton(button_t btn) {
	buzzTouch();

	if (btn == BUTTON_TL) {
		if (sensor_show_type == SENSOR_SHOW_TEMPERATURE) {
			sensor_show_type = SENSOR_SHOW_HUMIDTY;
			sensorButtonPressed(0x42); // xxh
		} else if (sensor_show_type == SENSOR_SHOW_HUMIDTY) {
			sensor_show_type = SENSOR_SHOW_CYCLE;
			sensorButtonPressed(0x43); // °Ch
		} else if (sensor_show_type == SENSOR_SHOW_CYCLE) {
			sensor_show_type = SENSOR_SHOW_TEMPERATURE;
			sensorButtonPressed(0x41); // xxh
		}

#if defined(DEBUG)
		printf("S: Changed type display: %d\n", sensor_show_type);
#endif
	}

	if (btn == BUTTON_TR) {
		if (sensor_show_value == SENSOR_SHOW_CURRENT) {
			sensor_show_value = SENSOR_SHOW_MIN;
			sensorButtonPressed(0x45); // Lo
		} else if (sensor_show_value == SENSOR_SHOW_MIN) {
			sensor_show_value = SENSOR_SHOW_MAX;
			sensorButtonPressed(0x46); // Hi
		} else if (sensor_show_value == SENSOR_SHOW_MAX) {
			sensor_show_value = SENSOR_SHOW_CURRENT;
			sensorButtonPressed(0x44); // Cur
		}

#if defined(DEBUG)
		printf("S: Changed value display: %d\n", sensor_show_value);
#endif
	}

	if (btn == BUTTON_BR) {
#if defined(DEBUG)
		printf("S: Clearing Values\n");
#endif
		sensorClear();
		sensorButtonPressed(0x49); // ---
	}

	if (btn == BUTTON_BL) {
#if defined(DEBUG)
		printf("S: Storing Config\n");
#endif
		eeSensorSet(sensor_show_type | (sensor_show_value << 4));
		sensorButtonPressed(0x4B); // UPd
	}

}

// -----------------------------------------------------------------------------------

void sensorI2CReset() {
	HAL_GPIO_WritePin(SENSOR_VCC_GPIO_Port, SENSOR_VCC_Pin, 0x00);
	HAL_Delay(500);
	HAL_GPIO_WritePin(SENSOR_VCC_GPIO_Port, SENSOR_VCC_Pin, 0x01);
	HAL_Delay(500);
}
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

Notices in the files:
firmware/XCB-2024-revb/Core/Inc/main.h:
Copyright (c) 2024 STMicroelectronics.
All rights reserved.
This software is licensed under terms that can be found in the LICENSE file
